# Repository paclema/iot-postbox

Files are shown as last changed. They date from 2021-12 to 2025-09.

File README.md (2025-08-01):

# IoT-PostBox



IoT-PostBox is a complete smart mailbox sensor solution that monitors mailbox activity and sends wireless notifications when events occur. The project consists of custom hardware designs with integrated battery management and charging system, and firmware that monitors switch sensors to detect mailbox events. The hardware has evolved from initial ESP8266-based designs (IoT-PostBox v0.x) to current ESP32S2-based designs (IoT-PostBox v1.x) with added LoRaWAN capabilities for extended range communication beyond WiFi and a optimized power management system. The device is designed for battery-powered operation with onboard charging circuitry. When an event is detected, the device wakes from deep sleep, connects wirelessly (WiFi or LoRa), publishes the event via MQTT or LoRaWAN, and returns to sleep to maximize battery life. The system includes device configuration and management through the WebConfigServer library, which provides a web-based dashboard to visualize data and handle device configurations easily using a config.json file.

**Installation and use:** The device is installed inside the mailbox with switches positioned to detect when the mail slot or door is opened. One switch can detect mail insertion (when the slot is opened to insert mail), while another can detect mail collection (when the mailbox door is opened to retrieve mail). This allows monitoring both mail delivery and pickup events.

**Hardware evolution:**
- **v0.x (ESP8266):** WiFi-only communication, basic power management using CH_PD pin to disable the microcontroller, battery charging system, switch sensor inputs.
- **v1.x (ESP32-S2):** Enhanced with LoRaWAN capability, improved power management with deep sleep modes managed by interrupts (allowing identification of wake-up source via WAKE_UP_BITMASK), advanced battery management, native USB programming, and expanded I/O options.

> [!NOTE]  
> For detailed hardware specifications, BOMs, and pinouts, see [`pcb_desings/readme.md`](pcb_desings/).

---

## 📁 Repository Structure

- `/src/` — Main firmware source code for IoT-PostBox
- `/pcb_desings/` — Hardware designs, documentation, BOMs, gerbers, and 3D models
- `/data/` — SPIFFS filesystem data (configs, static webapp, certificates)
- `/platformio.ini` — PlatformIO project configuration

---

## ⚡ Getting Started

1. **Select and configure your hardware:** 
   - **For IoT-PostBox PCBs:** Choose between IoT-PostBox v0.x (ESP8266-based) or IoT-PostBox v1.x (ESP32-S2-based) versions. See [`pcb_desings/readme.md`](pcb_desings/readme.md) for detailed specifications.
   - **For development boards:** The firmware also supports various ESP8266/ESP32 development boards (see available targets in `platformio.ini`), but full compatibility and functionality is only guaranteed with the custom IoT-PostBox PCBs designed for this purpose.
   - Configure the appropriate target in `platformio.ini` for your hardware version (e.g., `IoT-PostBox_v1` for IoT-PostBox v1.x PCB).
   - Edit `data/config/config.json` with your initial configuration (WiFi credentials, MQTT settings, etc.) following the WebConfigServer library standard.

2. **Upload SPIFFS data:**
   ```sh
   pio run -t uploadfs
   ```

3. **Build and upload firmware:** Use PlatformIO to compile and flash the firmware to your device.

4. **Configure the device:** Access the web dashboard hosted by the device for WiFi, MQTT, and power management setup, or update the configuration by editing `config.json` and re-uploading SPIFFS data.

---

## 📈 Web Dashboard

The static web dashboard is provided by the [WebConfigServer](https://github.com/paclema/WebConfigServer) library and served directly from the device.

If you need to customize the dashboard:
- Go to the WebConfigServer repository and follow the build instructions
- Copy the generated static files to the `/data/` folder
- Upload `/data/` to the device SPIFFS

---

## 📚 Dependencies

This project uses the following main libraries:
- [WebConfigServer](https://github.com/paclema/WebConfigServer) - Web dashboard and device configuration management
- [PowerManagement](https://github.com/paclema/PowerManagement) - Battery monitoring and power management

---

## 📄 License

[][cc-by-nc-sa]&nbsp;&nbsp;&nbsp;<a property="dct:title" rel="cc:attributionURL" href="https://github.com/paclema/iot-postbox"> IoT-PostBox</a> © 2019-2025 by <a rel="cc:attributionURL dct:creator" property="cc:attributionName" href="http://www.paclema.com/">paclema</a> is licensed under <a href="http://creativecommons.org/licenses/by-nc-sa/4.0/?ref=chooser-v1" target="_blank" rel="license noopener noreferrer" style="display:inline-block;">CC BY-NC-SA 4.0</a>

**Hardware and firmware designs** are provided for educational and non-commercial use. For commercial use, please contact the author for permission.

[cc-by-nc-sa]: http://creativecommons.org/licenses/by-nc-sa/4.0/
[cc-by-nc-sa-image]: https://licensebuttons.net/l/by-nc-sa/4.0/88x31.png

---

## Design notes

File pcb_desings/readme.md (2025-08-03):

# IoT-PostBox PCB Designs

This folder contains all hardware designs for the IoT-PostBox project. These PCBs are intended for ultra-low power event detection and wireless notification, ideal for smart mailboxes or similar battery-powered IoT applications. The boards are designed to maximize battery life by staying in deep sleep and only waking up when an event is detected.  
**Typical use case:** Mount a switch at the mailbox slot or door to detect when a letter or package is inserted, triggering a wireless notification.

---

## 📝 How It Works

- **Event Detection:** The boards monitor switches (J1/J2) for events such as mailbox opening or mail insertion.
- **Wake-Up:** ESP8266 boards power on from switches, ESP32-S2 boards wake from deep sleep via GPIO interrupts
- **Notification:** Events are sent wirelessly (WiFi/MQTT for ESP8266, WiFi/MQTT and LoRaWAN for ESP32-S2)
- **Power Management:** Battery charging and monitoring circuits ensure safe operation and long battery life.

---

## 📦 IoT-Postbox v0.X (ESP8266/ESP-12)

- **Folder:** [`iot-postbox/`](iot-postbox/)
- **MCU:** ESP8266 (ESP-12F or ESP-07S)
- **Wake-up:** When either switch input (J1 or J2) closes, it physically pulls the CH_PD pin high, powering on the ESP8266 from a completely powered-down state. Once powered on, the firmware immediately activates GPIO14 to maintain CH_PD high, ensuring the system stays powered even if the switch opens during the notification process. After completing the notification and a configured delay, GPIO14 goes low, completely powering down the ESP8266 for maximum battery savings. The board can also be configured for deep sleep mode or continuous operation instead of complete power down via the onboard web app.
- **Features:**
  - Battery charger (TP4056) with overcharge, overdischarge, and overcurrent protection
  - Power management with LDO (candidates: ME6211 or MCP1700)
  - Switch sensor inputs for mailbox event detection
  - Deep sleep and wake-up logic via GPIO
  - WiFi and MQTT notifications for remote monitoring
- **Versions:**
  | v0.0 | v0.3 |
  |:----:|:----:|
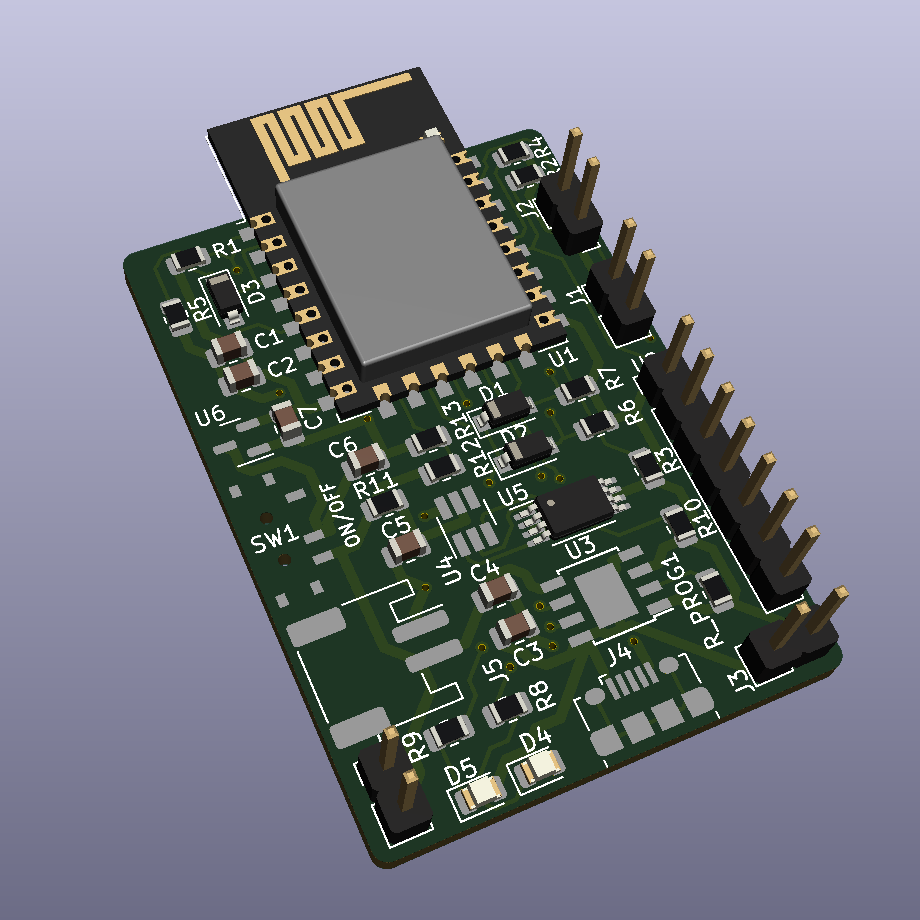
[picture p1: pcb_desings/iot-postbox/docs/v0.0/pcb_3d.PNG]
v0.0
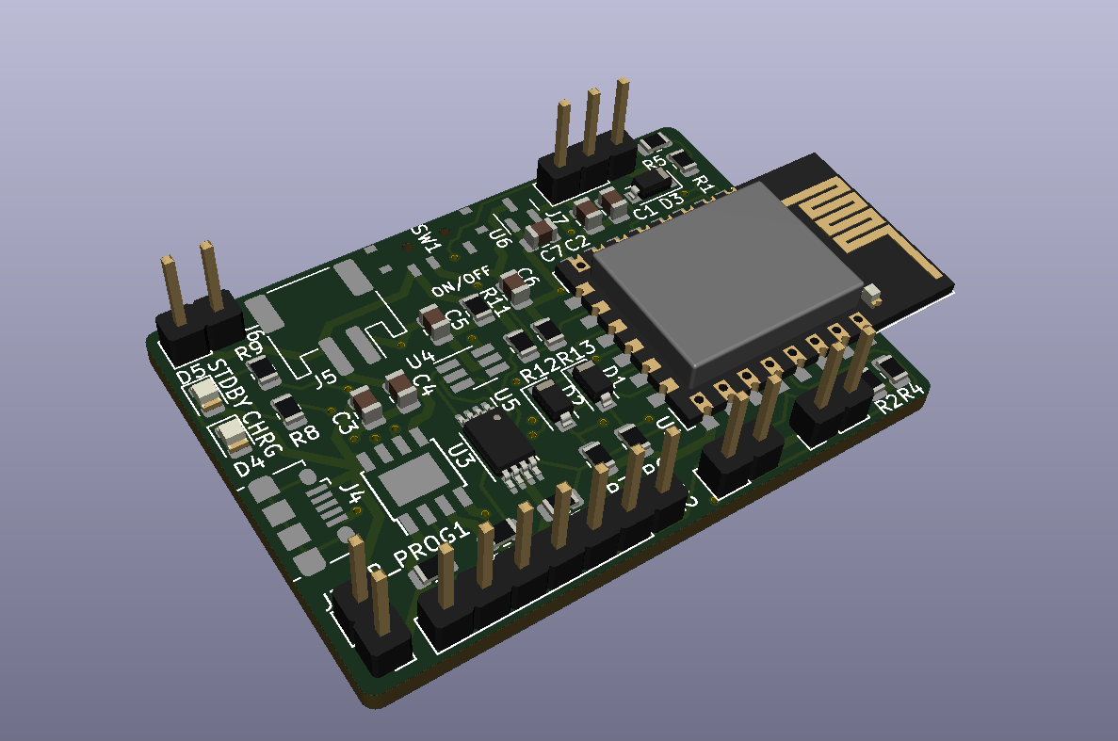
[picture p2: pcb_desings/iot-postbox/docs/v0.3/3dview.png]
v0.3
  |  |  |
  | *First version* <br> Basic mailbox sensor with battery charger and power management. | *Added WS2812B LED strip for notifications* <br> *Updated battery sense resistors for improved ADC accuracy* <br> *Changed switch pinouts for better integration* |

- **Programming & Debugging:**  
  For ESP8266-based boards, external programming is required. Two options available:
  
  **Option 1: TTL-to-USB Adapter + FTDI Breakout**
  | Top View | Bottom View |
  |:------------------:|:----------------:|
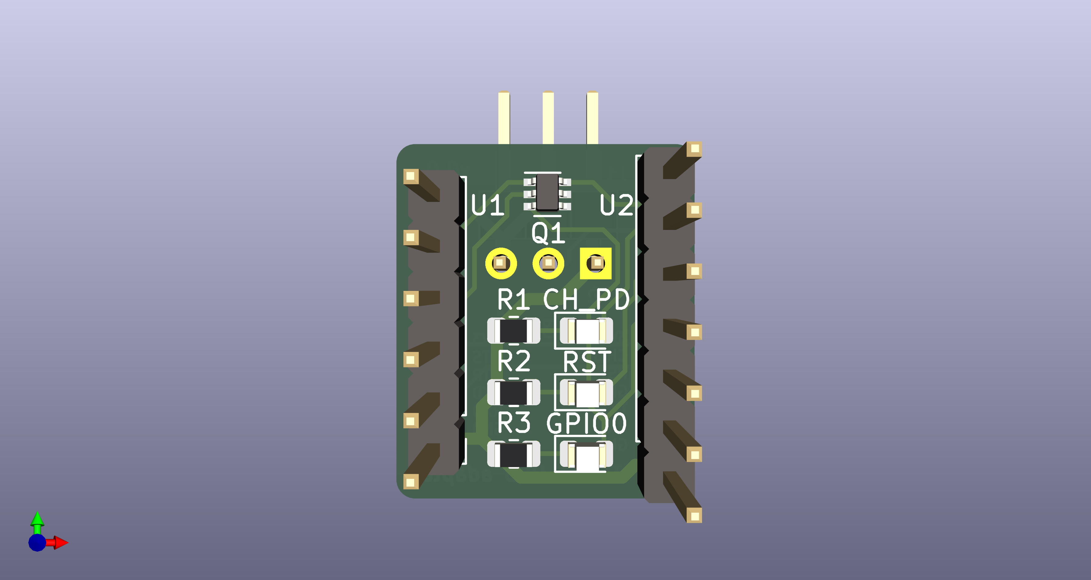
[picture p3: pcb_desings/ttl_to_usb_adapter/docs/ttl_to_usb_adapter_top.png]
TTL Adapter TTL to USB Adapter
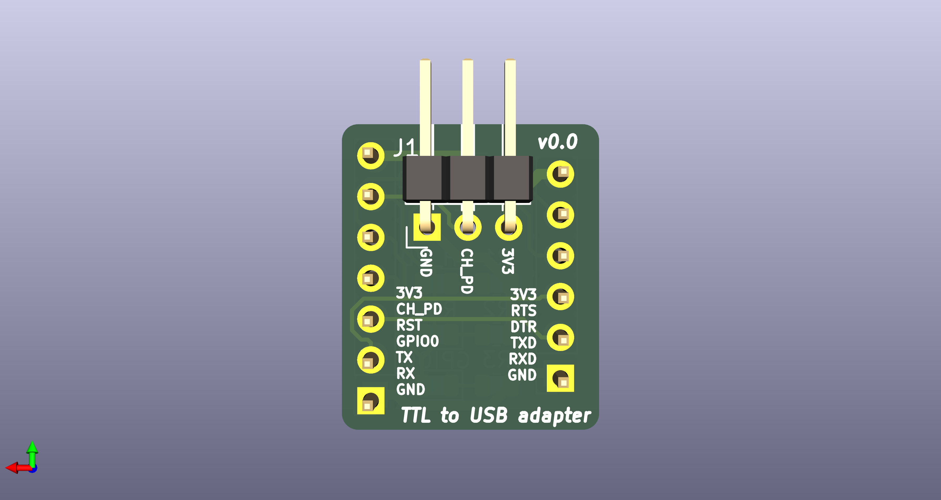
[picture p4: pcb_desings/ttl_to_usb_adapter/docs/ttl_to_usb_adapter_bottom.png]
TTL Adapter SMD
  |  |  |
  - **Repository:** [`ttl_to_usb_adapter/`](ttl_to_usb_adapter/)
  - Converts DTR/RTS signals from an USB to Serial FTDI breakout board to ESP8266 boot sequence
  - Dedicated jumper for CH_PD control during programming

  **Option 2: Integrated USB Bridge**
  - **USBtoUART:** Complete solution available at [paclema.com/projects/usbtouart/](https://paclema.com/projects/usbtouart/) or at github.com/paclema/USBtoUART
  - Single device with integrated USB-to-UART conversion

---

## 📦 IoT-Postbox v1 (ESP32-S2)

- **Folder:** [`iot-postbox_v1/`](iot-postbox_v1/)
- **MCU:** ESP32-S2
- **Wake-up:** Switches (J1/J2) are configured as GPIO interrupts to wake up the MCU from deep sleep, instead of physically powering on the board (as in ESP8266). This allows more flexible event handling and enables distinguishing between different events.
- **Features:**
  - LoRa support (RFM95W module footprints)
  - Up to 16MB flash and 8MB PSRAM (optional, depending on SoC version)
  - Improved battery and power management (dedicated ADC sense for VBAT and VBUS)
  - Modular schematic split into INTERFACE, MCU, and POWER sections
  - Selectable onboard/uFL antennas for WiFi (JP1) and LoRa (JP2) by populating the correct resistor
  - Dedicated JTAG debug port
  - Multiple jumpers and test points on the back for configuration and debugging (including RPROG selection for battery charger IC)

- **Latest version:** IoT-PostBox v1.2
  | Top View | Bottom View |
  |:--------------:|:----------------:|
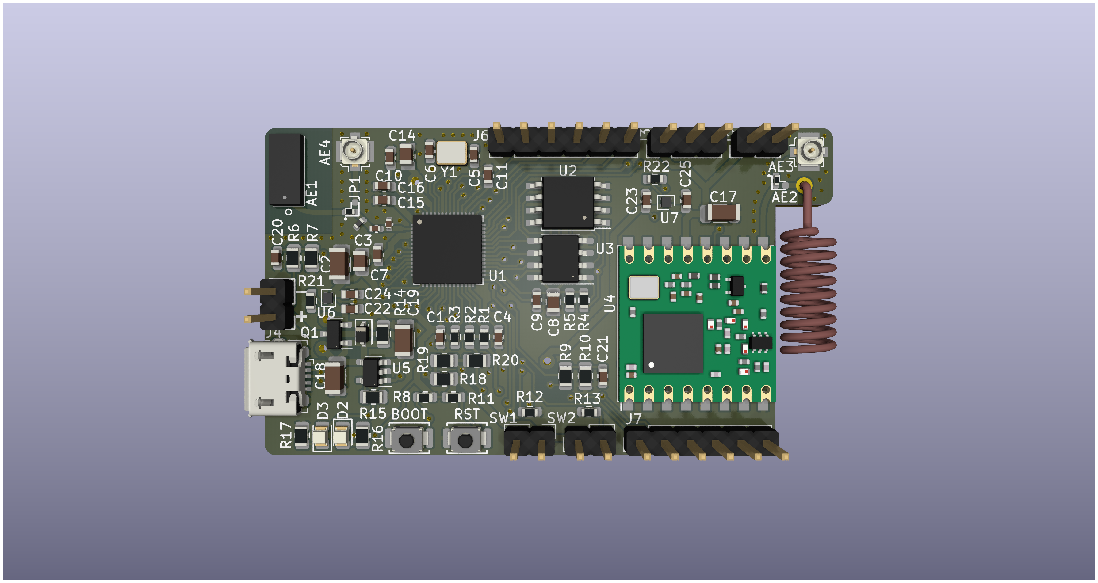
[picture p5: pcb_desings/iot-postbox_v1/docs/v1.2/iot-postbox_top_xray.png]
Top v1.2 Top
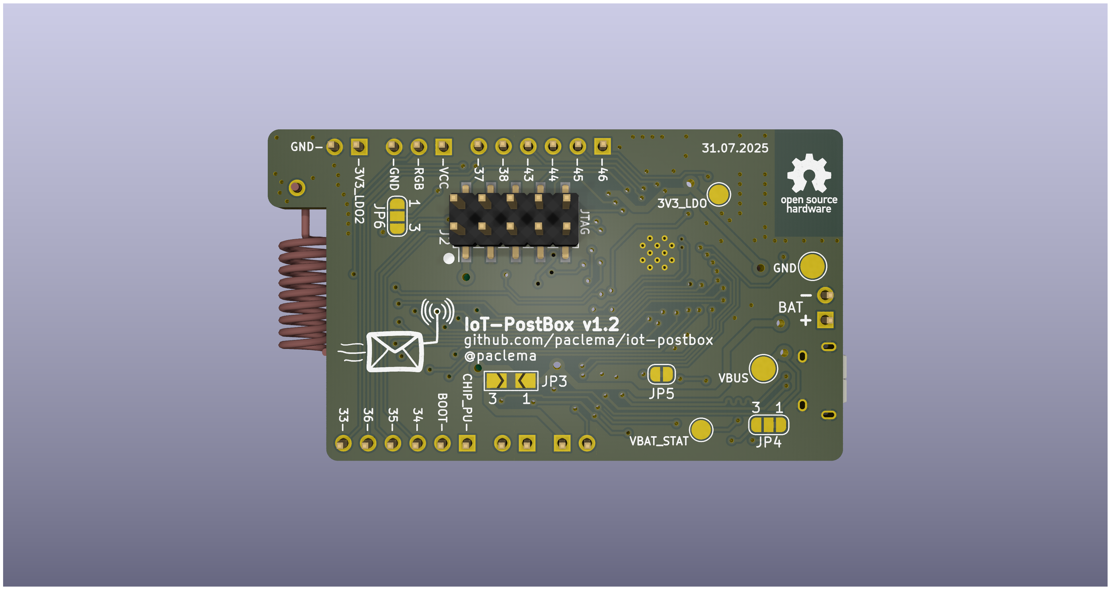
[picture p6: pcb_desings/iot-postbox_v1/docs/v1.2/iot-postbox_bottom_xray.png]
Bottom v1.2 Bottom
  |  |  |

- **Programming & Debugging:**  
  Programming and debugging for the ESP32-S2 board does **not require an external USB-to-UART bridge**. The ESP32-S2 features a native USB interface (USB-CDC/JTAG), allowing direct programming and serial communication via the onboard USB connector. Simply connect the board to your computer using a USB cable for firmware flashing and debugging.

### LiPo Charger & RPROG Selection

The onboard charger circuit is designed to be compatible with MCP73831/2, TP4054, and TP4065 ICs, allowing any of these to be used. The charging current is set by the RPROG resistor.

- **For MCP73831/2 (max 500mA) and TP4054 (max 800mA):**
  ```
  Ichg (mA) = 1000(v) / R(kΩ)
  ```
  | RPROG (Ω) | Charging Current (mA) |
  |-----------|----------------------|
  | 10k       | 100                  |
  | 5k        | 200                  |
  | 2k2       | 455                  |
  | 2k        | 500                  |
  | 1k        | 1000                 |

- **For TP4065 (max 600mA):**
  ```
  Ichg (mA) = 1100(v) / R(kΩ)
  ```
  | RPROG (Ω) | Charging Current (mA) |
  |-----------|----------------------|
  | 2k2       | 500                  |
  | 2k        | 600                  |

- **Note:**  
  - Choose the RPROG value based on your battery's specifications and desired charging speed.
  - Protections: Battery and input reverse polarity protection but no temperature or overcurrent protection.

- **VBAT_STAT output:**  
  - Tri-state output: for MCP73831.
  - Open-drain output: for MCP7383, TP4054 and TP4065.
  - Only for open-drain, `R18` makes sense because VDD_STAT can be configurable only in that case.
  - Monitored using ESP32-S2 GPIO3/ADC1_CH2 pin.

### Pinout Reference (IoT-Postbox v1.2)

Below are the pinouts for the main connectors on the back of the IoT-Postbox v1.2 PCB, including signal and ESP32-S2 functions:

#### J6 (EXT1 Expansion Port):

| Pin | Signal | Function |
|-----|---|---|
| 1 | GPIO46 | Strapping pin (can be used for boot mode selection) |
| 2 | GPIO45 | Strapping pin (can be used for VDD_SPI selection) |
| 3 | GPIO44 | UART0 RXD (default) |
| 4 | GPIO43 | UART0 TXD (default) |
| 5 | GPIO38 | I2C SCL (default) |
| 6 | GPIO37 | SPI MISO (default) |

#### J3 (LED Port):

| Pin | Signal | Function |
|-----|---|---|
| 1 | VCC | Power for LED strip (3V3_LDO2) |
| 2 | RGB_LED_PWM | PWM output for RGB LED strip |
| 3 | GND | Ground |

#### J5 (Power Output Port):

| Pin | Signal | Function |
|-----|---|---|
| 1 | 3V3_LDO2 | Power output from peripheral LDO |
| 2 | GND | Ground |

#### SW1 (Switch Sensor 1):

| Pin | Signal | Function |
|-----|---|---|
| 1 | 3V3_LDO  | Power for switch sensor |
| 2 | SW1 | Digital input (event detection, GPIO input) |

#### SW2 (Switch Sensor 2):

| Pin | Signal | Function |
|-----|---|---|
| 1 | 3V3_LDO  | Power for switch sensor |
| 2 | SW2 | Digital input (event detection, GPIO input) |

#### J7 (EXT2 Expansion Port):

| Pin | Signal | Function |
|-----|---|---|
| 1 | CHIP_PU  | ESP32-S2 enable (power up, active high) |
| 2 | BOOT | Boot mode selection (GPIO0, strapping pin) |
| 3 | GPIO34 | SPI MOSI (default) |
| 4 | GPIO35 | SPI SCK (default) |
| 5 | GPIO36 | SPI CS (default) |
| 6 | GPIO33 | I2C SDA (default) |

---

### 📚 Libraries

- **Folder:** [`libs/`](libs/)
- Contains KiCad symbols, footprints and 3D models, including Espressif official libraries and miscellaneous modules.

---

### 🛠️ Submodules Installation for KiCad

To pull KiCad lib submodules, run:
```sh
git submodule update --init --recursive
```

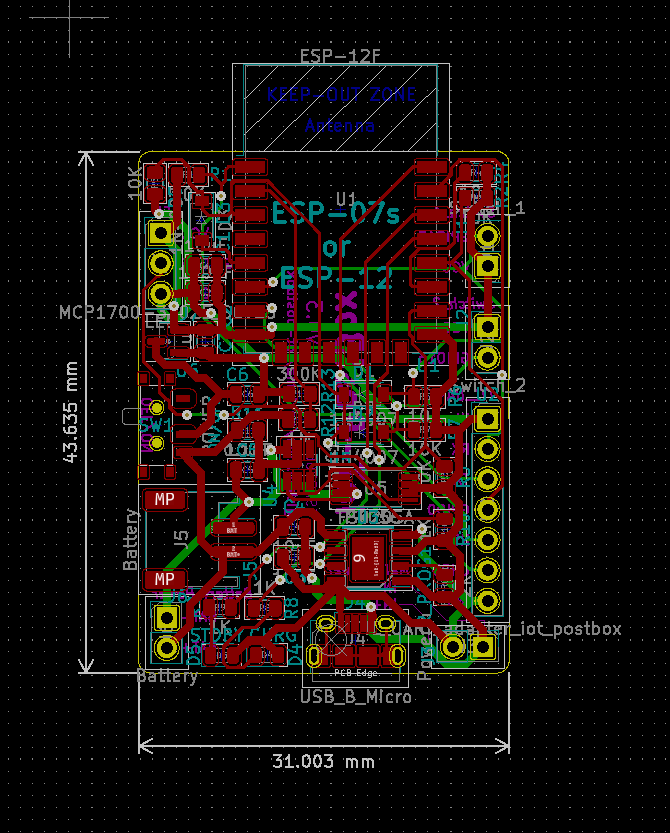
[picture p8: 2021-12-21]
pcb_desings/iot-postbox/docs/v0.3/pcb_view.png

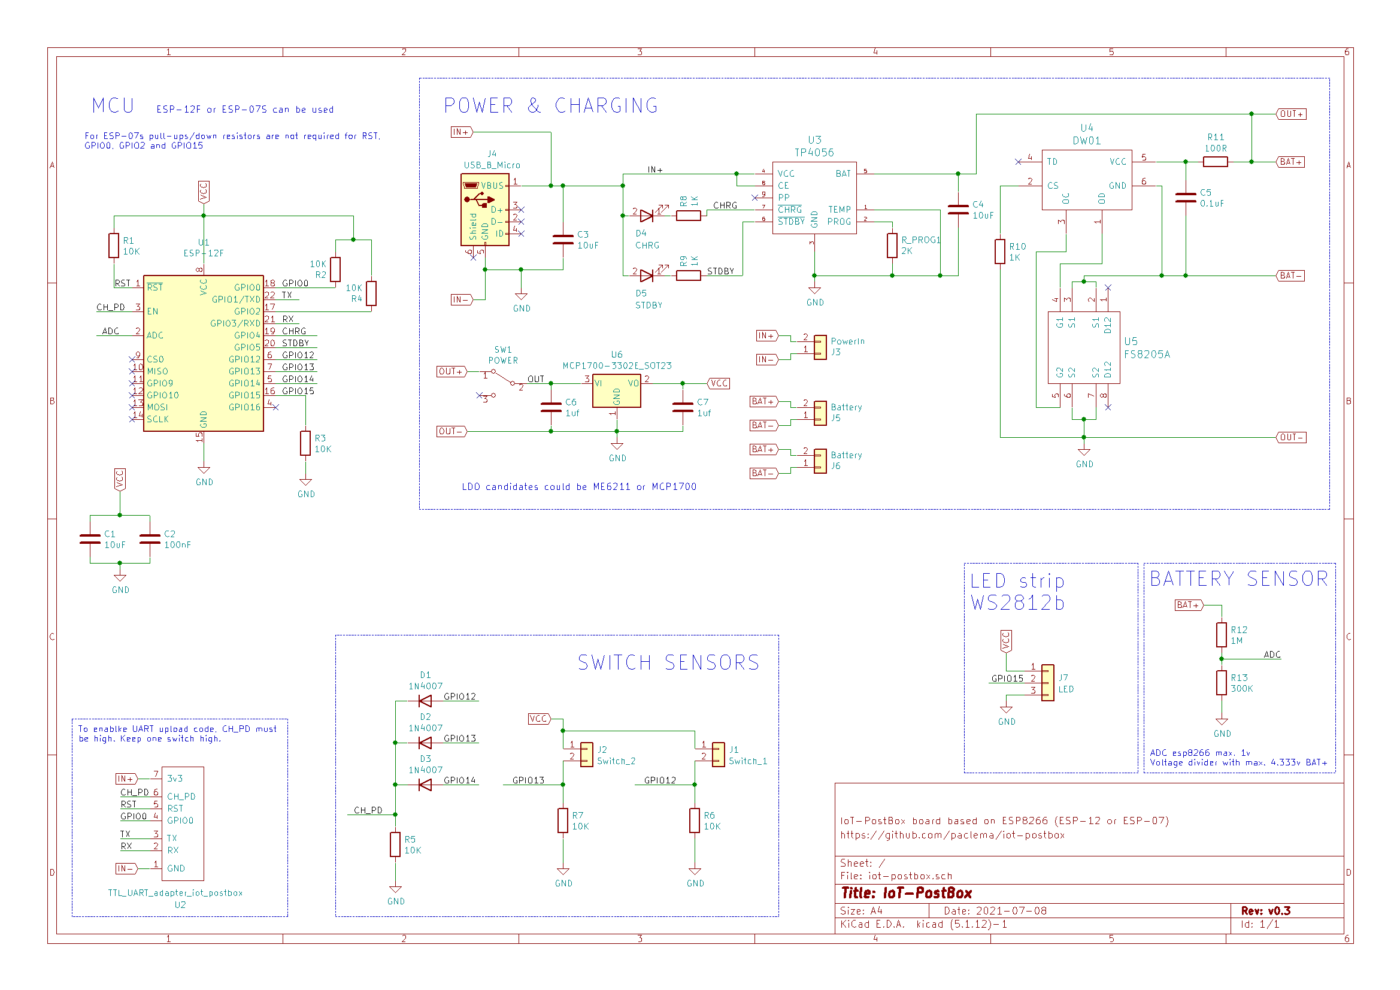
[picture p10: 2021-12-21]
pcb_desings/iot-postbox/docs/v0.3/sch_view.png

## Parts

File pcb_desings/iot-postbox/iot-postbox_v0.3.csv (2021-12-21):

Id | Designator | Package | Quantity | Designation | Supplier and ref
1 | J7 | PinHeader_1x03_P2.54mm_Vertical | 1 | LED
2 | U2 | PinHeader_1x07_P2.54mm_Vertical | 1 | TTL_UART_adapter_iot_postbox
3 | SW1 | 1P2T_SPDT_MSK-C02_7pin | 1 | POWER
4 | U6 | SOT-23 | 1 | MCP1700-3302E_SOT23
5 | U5 | TSSOP-8_4.4x3mm_P0.65mm | 1 | FS8205A
6 | U4 | SOT-23-6_Handsoldering | 1 | DW01
7 | U3 | TP4056_SOP-8-PP | 1 | TP4056
8 | U1 | ESP-12E | 1 | ESP-12F
9 | R_PROG1 | R_0805_2012Metric | 1 | 2K
10 | R13 | R_0805_2012Metric | 1 | 300K
11 | R12 | R_0805_2012Metric | 1 | 1M
12 | R11 | R_0805_2012Metric | 1 | 100R
13 | R10,R9,R8 | R_0805_2012Metric | 3 | 1K
14 | R6,R7,R5,R4,R3,R2,R1 | R_0805_2012Metric | 7 | 10K
15 | J6 | PinHeader_1x02_P2.54mm_Vertical | 1 | Battery
16 | J5 | JST_PH_S2B-PH-SM4-TB_1x02-1MP_P2.00mm_Horizontal | 1 | Battery
17 | J4 | USB_Micro-B_Amphenol_10118194_Horizontal | 1 | USB_B_Micro
18 | J3 | PinHeader_1x02_P2.54mm_Vertical | 1 | PowerIn
19 | J1 | PinHeader_1x02_P2.54mm_Vertical | 1 | Switch_1
20 | J2 | PinHeader_1x02_P2.54mm_Vertical | 1 | Switch_2
21 | D5 | LED_0805_2012Metric | 1 | STDBY
22 | D4 | LED_0805_2012Metric | 1 | CHRG
23 | D3,D2,D1 | D_SOD-123 | 3 | 1N4007
24 | C7,C6 | C_0805_2012Metric | 2 | 1uf
25 | C5 | C_0805_2012Metric | 1 | 0.1uF
26 | C4,C3,C1 | C_0805_2012Metric | 3 | 10uF
27 | C2 | C_0805_2012Metric | 1 | 100nF

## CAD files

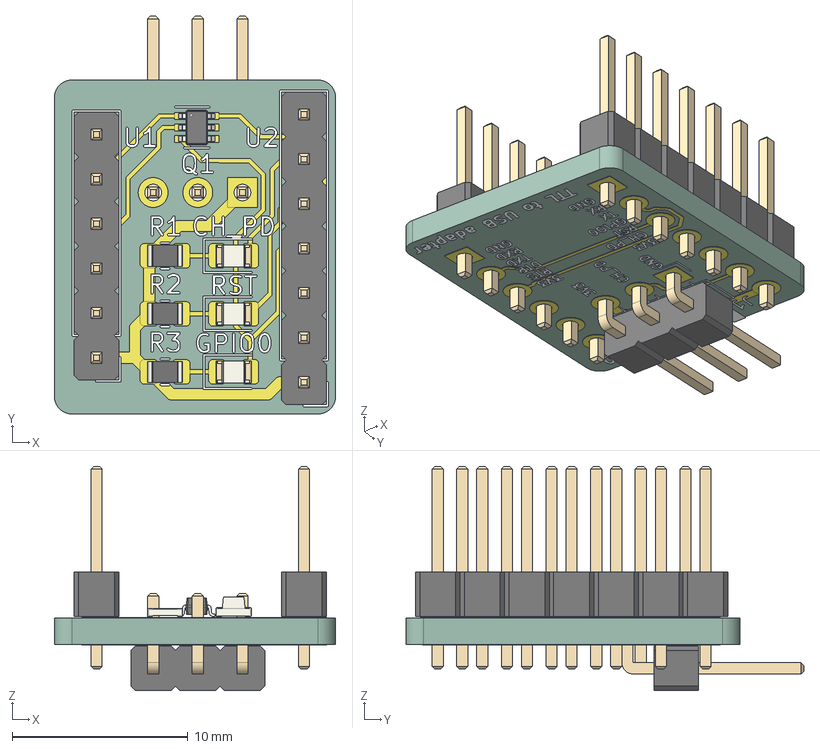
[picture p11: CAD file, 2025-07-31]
pcb_desings/ttl_to_usb_adapter/docs/ttl_to_usb_adapter.step
16.0 x 22.6 x 12.8 mm
PinHeader_1x06_P2.54mm_Vertical
SOT-363_SC-70-6
LED_0805_2012Metric x 3
R_0805_2012Metric x 3
PinHeader_1x07_P2.54mm_Vertical
PinHeader_1x03_P2.54mm_Horizontal
ttl_to_usb_adapter_copper
ttl_to_usb_adapter_silkscreen
ttl_to_usb_adapter_PCB

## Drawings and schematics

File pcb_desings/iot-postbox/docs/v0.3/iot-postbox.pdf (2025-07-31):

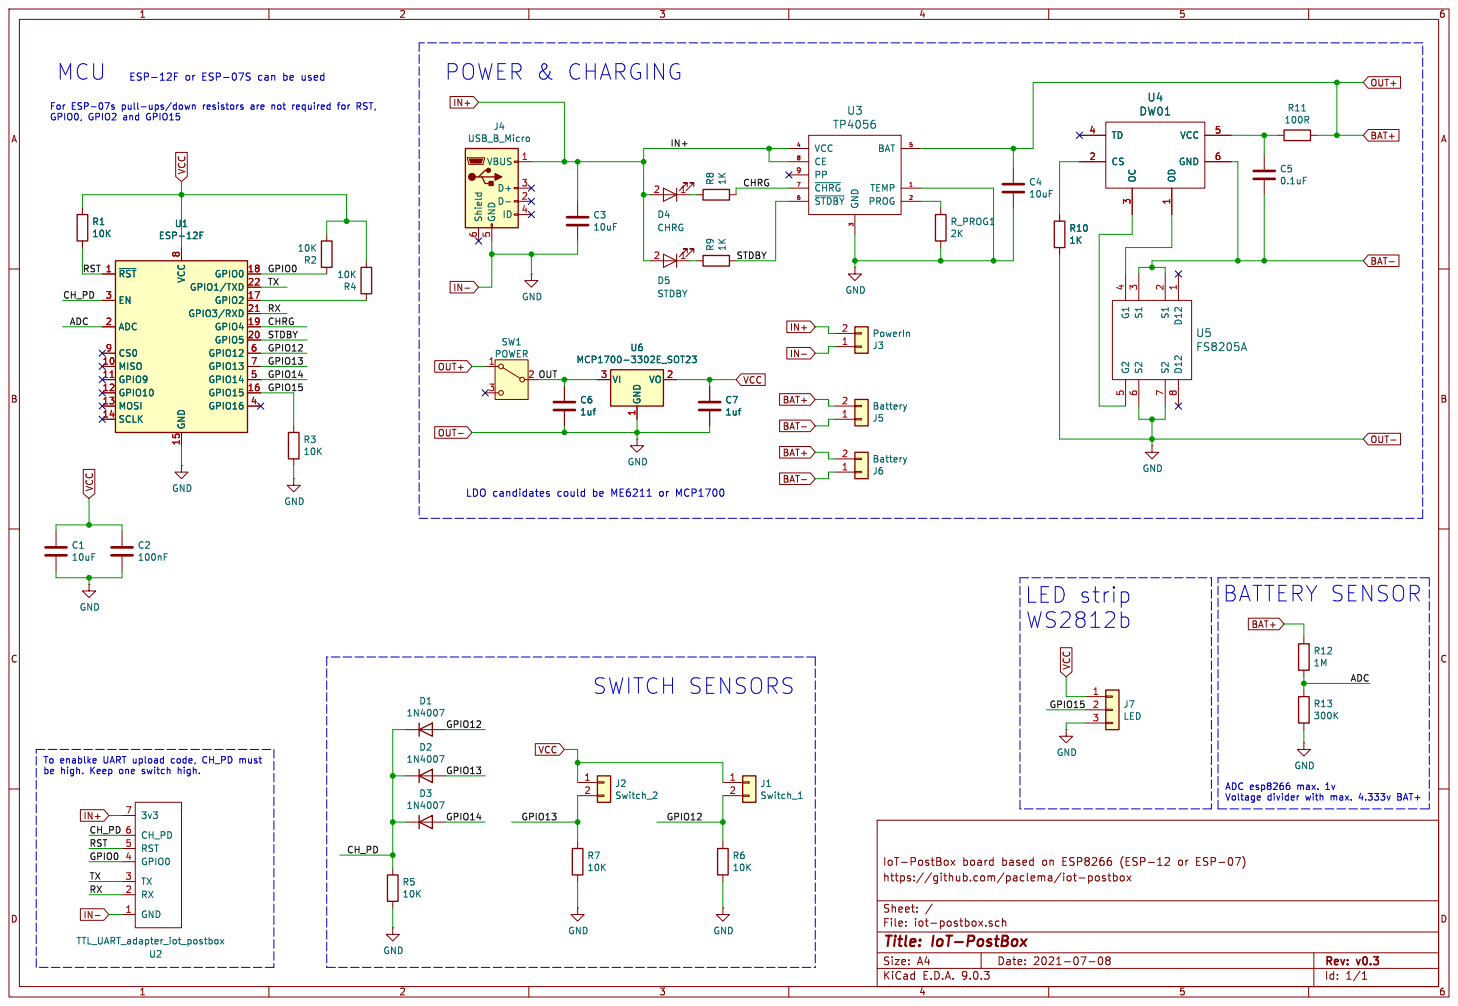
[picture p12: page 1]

BAT- BAT+ OUT+ OUT- BAT+ BAT-

8 GND 15 GPIO0 18 GPIO1/TXD 22 GPIO2 17 GPIO3/RXD 21 GPIO4 19 GPIO5 20 GPIO12 6 GPIO13 7 GPIO14 5 GPIO15 16 GPIO16 4 U1 ESP-12F

8 GND 15 GPIO0 18 GPIO1/TXD 22 GPIO2 17 GPIO3/RXD 21 GPIO4 19 GPIO5 20 GPIO12 6 GPIO13 7 GPIO14 5 GPIO15 16 GPIO16 4 U6 MCP1700-3302E_SOT23 VI 3 GND

File: iot-postbox.sch Sheet: / https://github.com/paclema/iot-postbox

Id: 1/1 Title: IoT-PostBox

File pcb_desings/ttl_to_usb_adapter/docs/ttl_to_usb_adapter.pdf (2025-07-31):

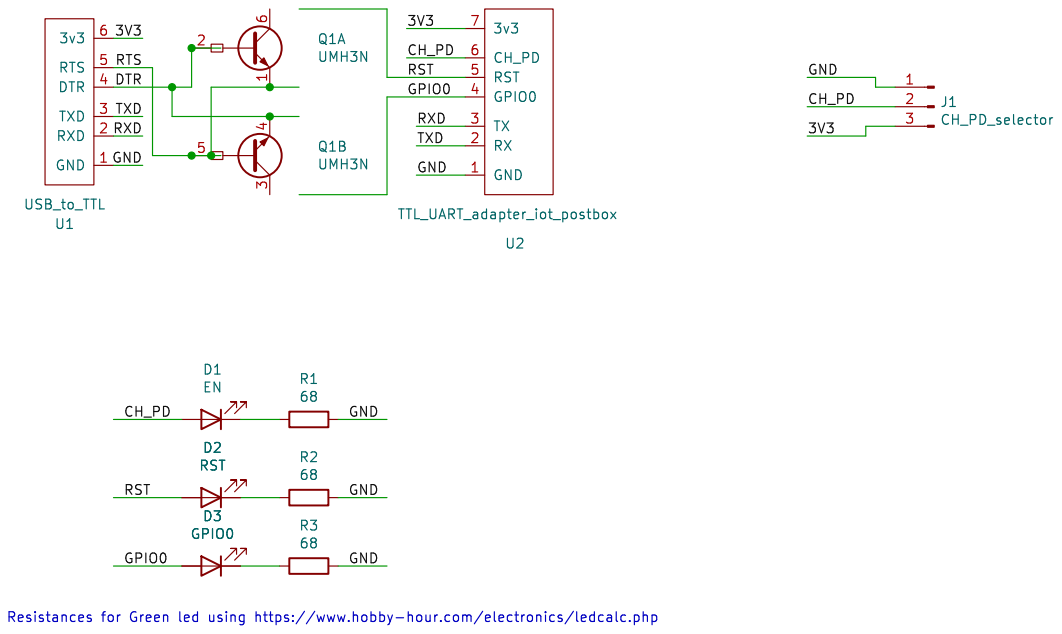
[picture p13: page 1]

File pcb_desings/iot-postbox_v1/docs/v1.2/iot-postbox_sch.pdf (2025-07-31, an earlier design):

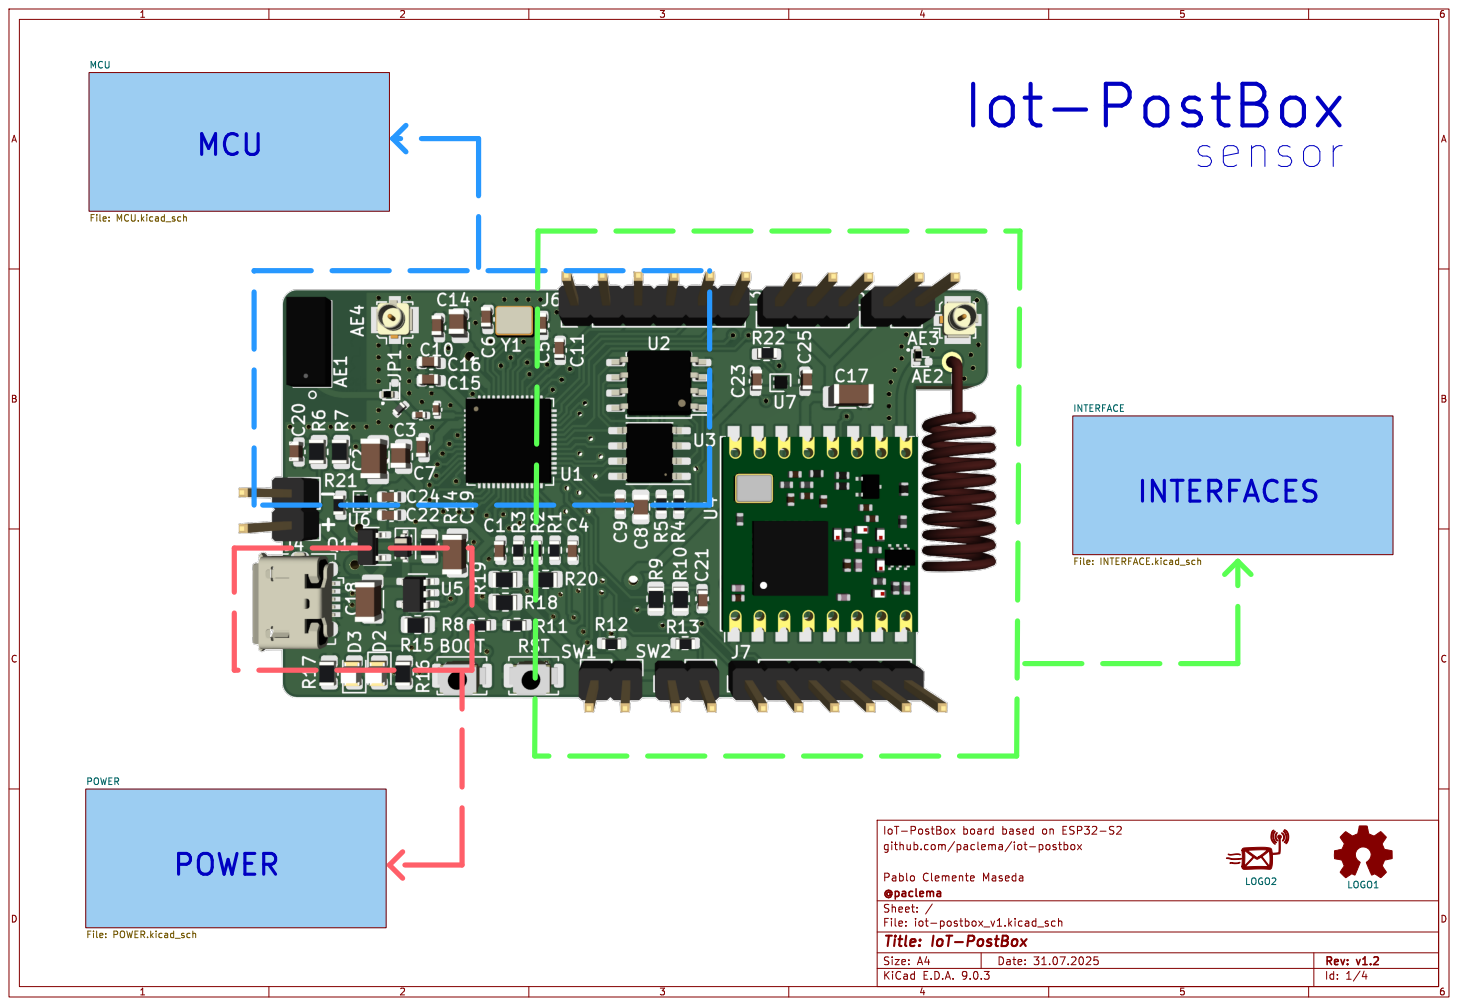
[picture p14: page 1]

github.com/paclema/iot-postbox

POWER

File: iot-postbox_v1.kicad_sch Sheet: / @paclema Pablo Clemente | Maseda

Id: 1/4 Title: IoT-PostBox

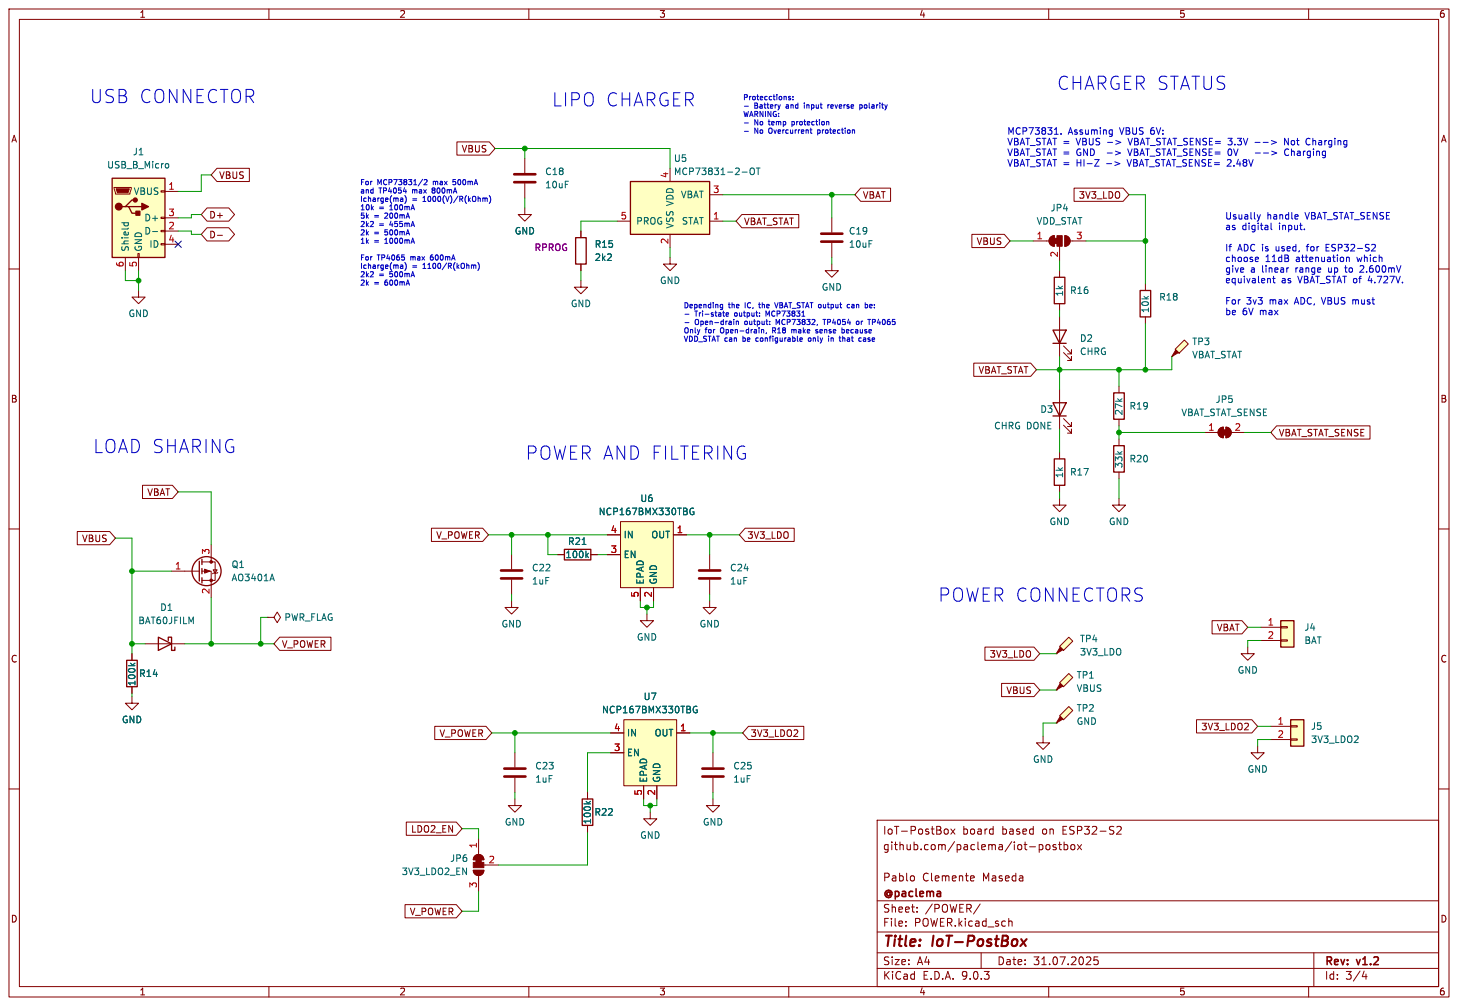
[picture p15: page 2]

Protecctions: - Battery and input reverse polarity WARNING: - No temp protection
100k VBUS
100k GND
2k2 RPROG

2 VBAT 3 STAT 1 U5 MCP73831-2-OT GND

If ADC is used, for ESP32-S2
give a linear range up to 2.600mV

GND GND

github.com/paclema/iot-postbox

Id: 3/4 Title: IoT-PostBox

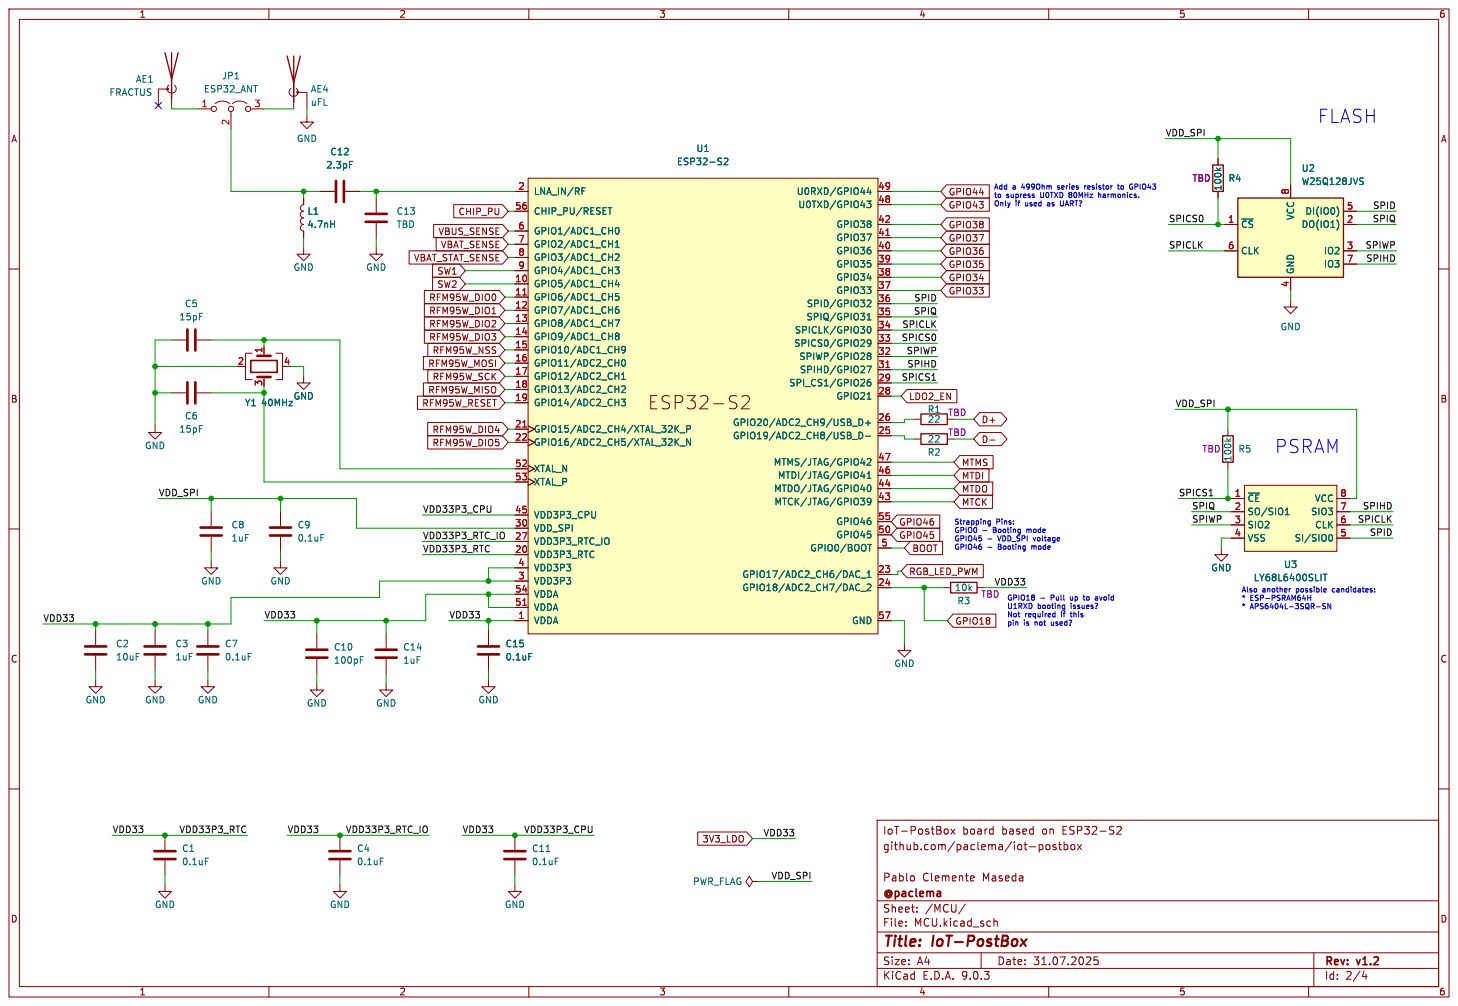
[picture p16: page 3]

github.com/paclema/iot-postbox

Id: 2/4 Title: IoT-PostBox

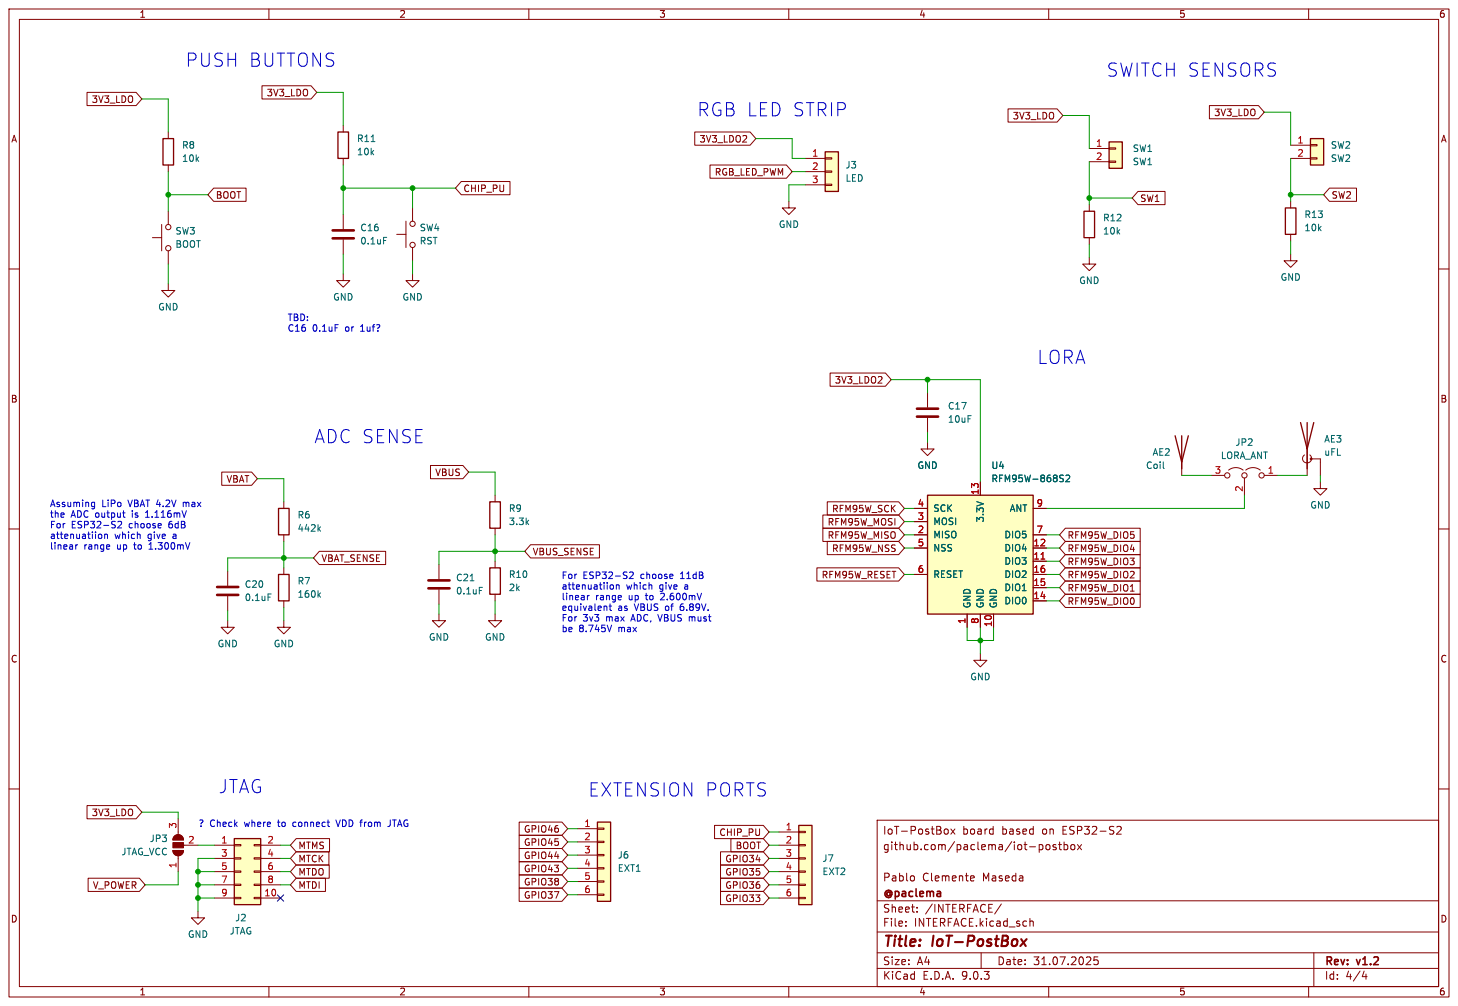
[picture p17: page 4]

Assuming LiPo VBAT 4.2V max
the ADC output is 1.116mV

linear range up to 2.600mV

github.com/paclema/iot-postbox

Id: 4/4 Title: IoT-PostBox

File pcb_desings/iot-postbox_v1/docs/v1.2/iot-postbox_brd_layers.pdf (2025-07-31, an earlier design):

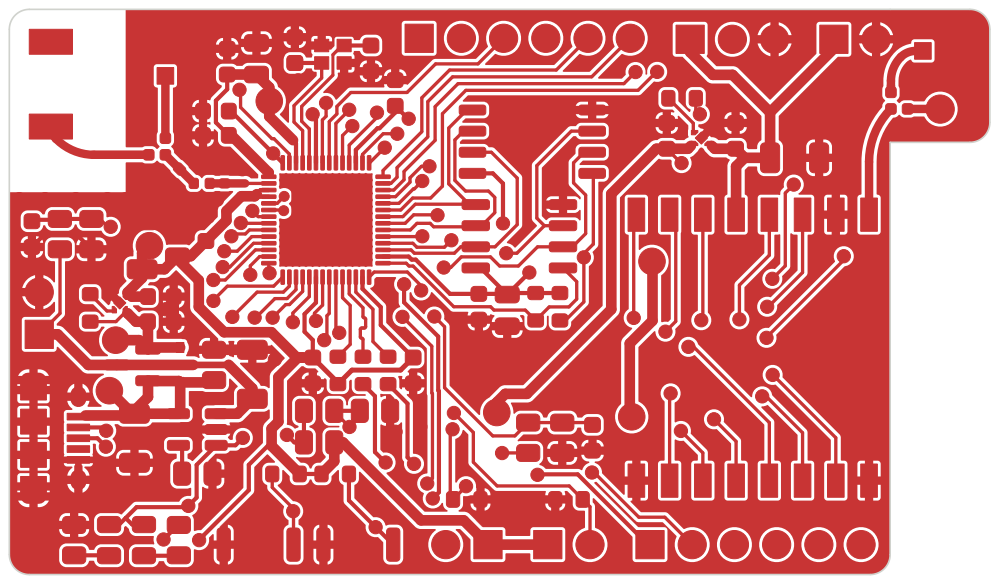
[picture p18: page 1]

github.com/paclema/iot-postbox

Id: 1/11 Title: IoT-PostBox

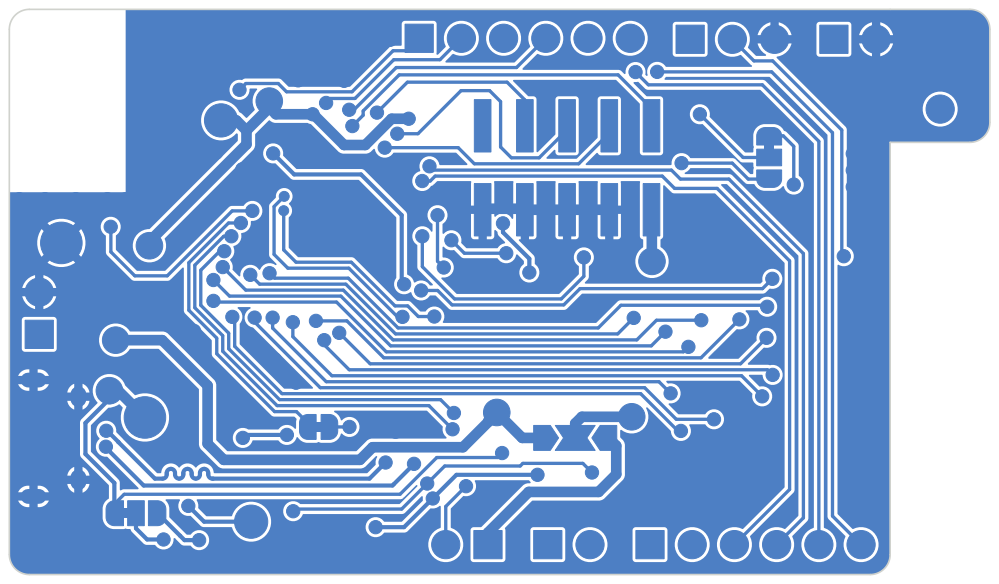
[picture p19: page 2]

github.com/paclema/iot-postbox

Id: 2/11 Title: IoT-PostBox

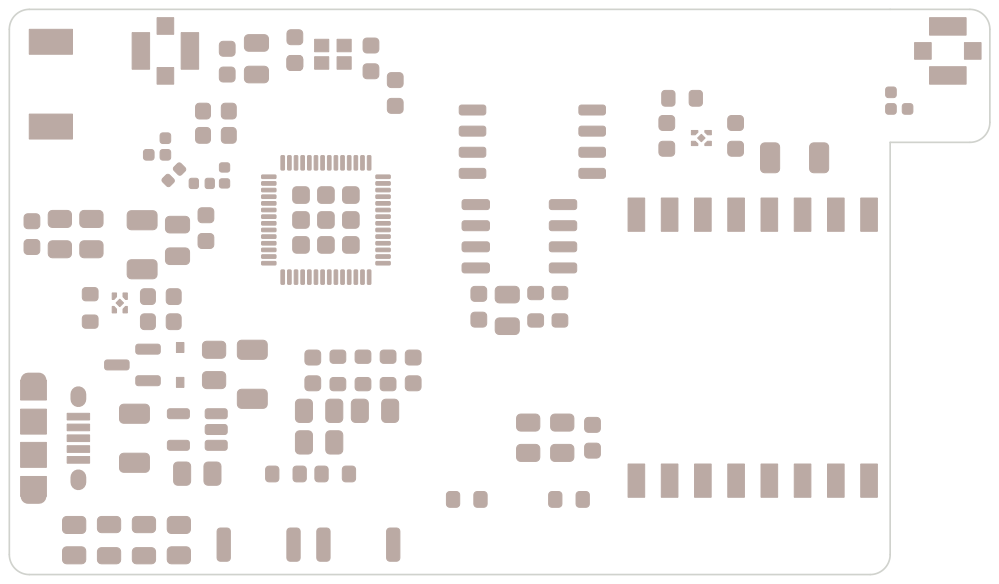
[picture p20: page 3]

github.com/paclema/iot-postbox

Id: 3/11 Title: IoT-PostBox

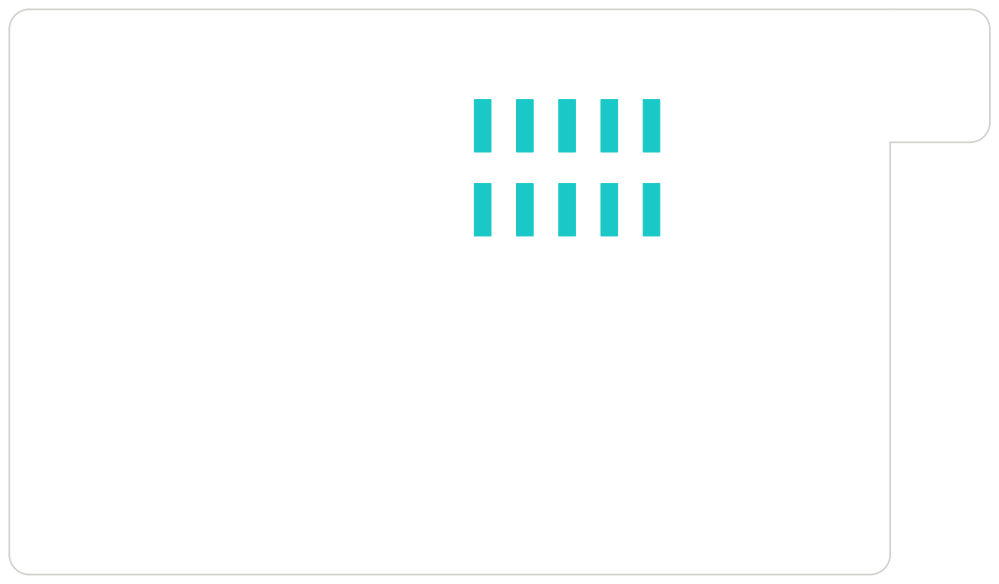
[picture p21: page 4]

github.com/paclema/iot-postbox

Id: 4/11 Title: IoT-PostBox

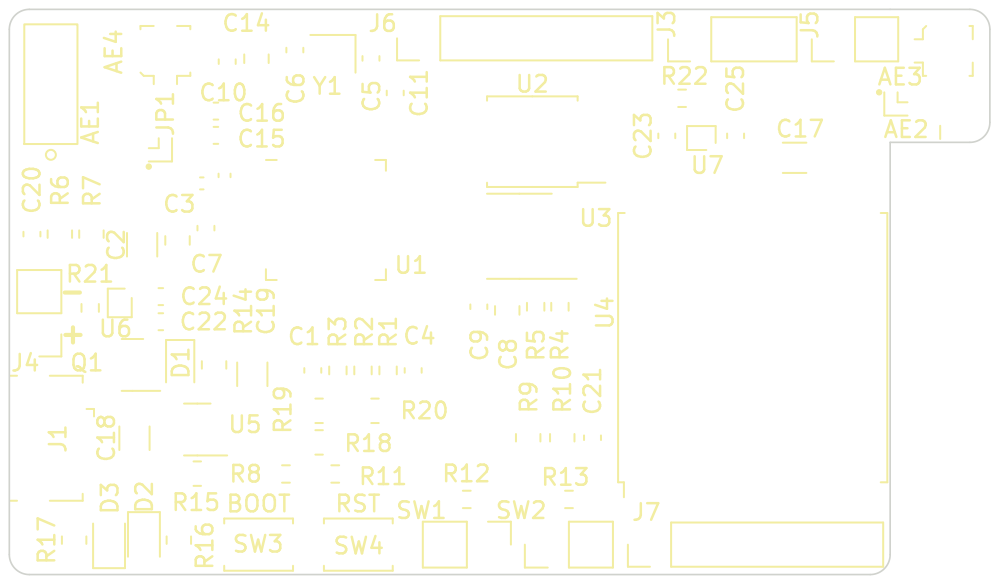
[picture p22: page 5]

github.com/paclema/iot-postbox

Id: 5/11 Title: IoT-PostBox

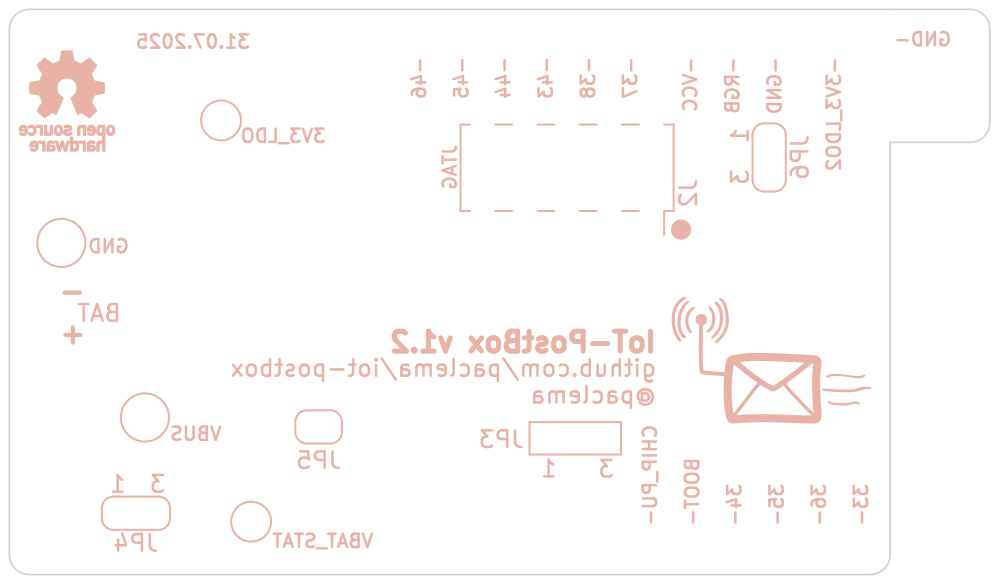
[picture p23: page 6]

github.com/paclema/iot-postbox

Id: 6/11 Title: IoT-PostBox


github.com/paclema/iot-postbox

Id: 7/11 Title: IoT-PostBox


github.com/paclema/iot-postbox

Id: 8/11 Title: IoT-PostBox


github.com/paclema/iot-postbox

Id: 9/11 Title: IoT-PostBox


github.com/paclema/iot-postbox

Id: 10/11 Title: IoT-PostBox


github.com/paclema/iot-postbox

Id: 11/11 Title: IoT-PostBox







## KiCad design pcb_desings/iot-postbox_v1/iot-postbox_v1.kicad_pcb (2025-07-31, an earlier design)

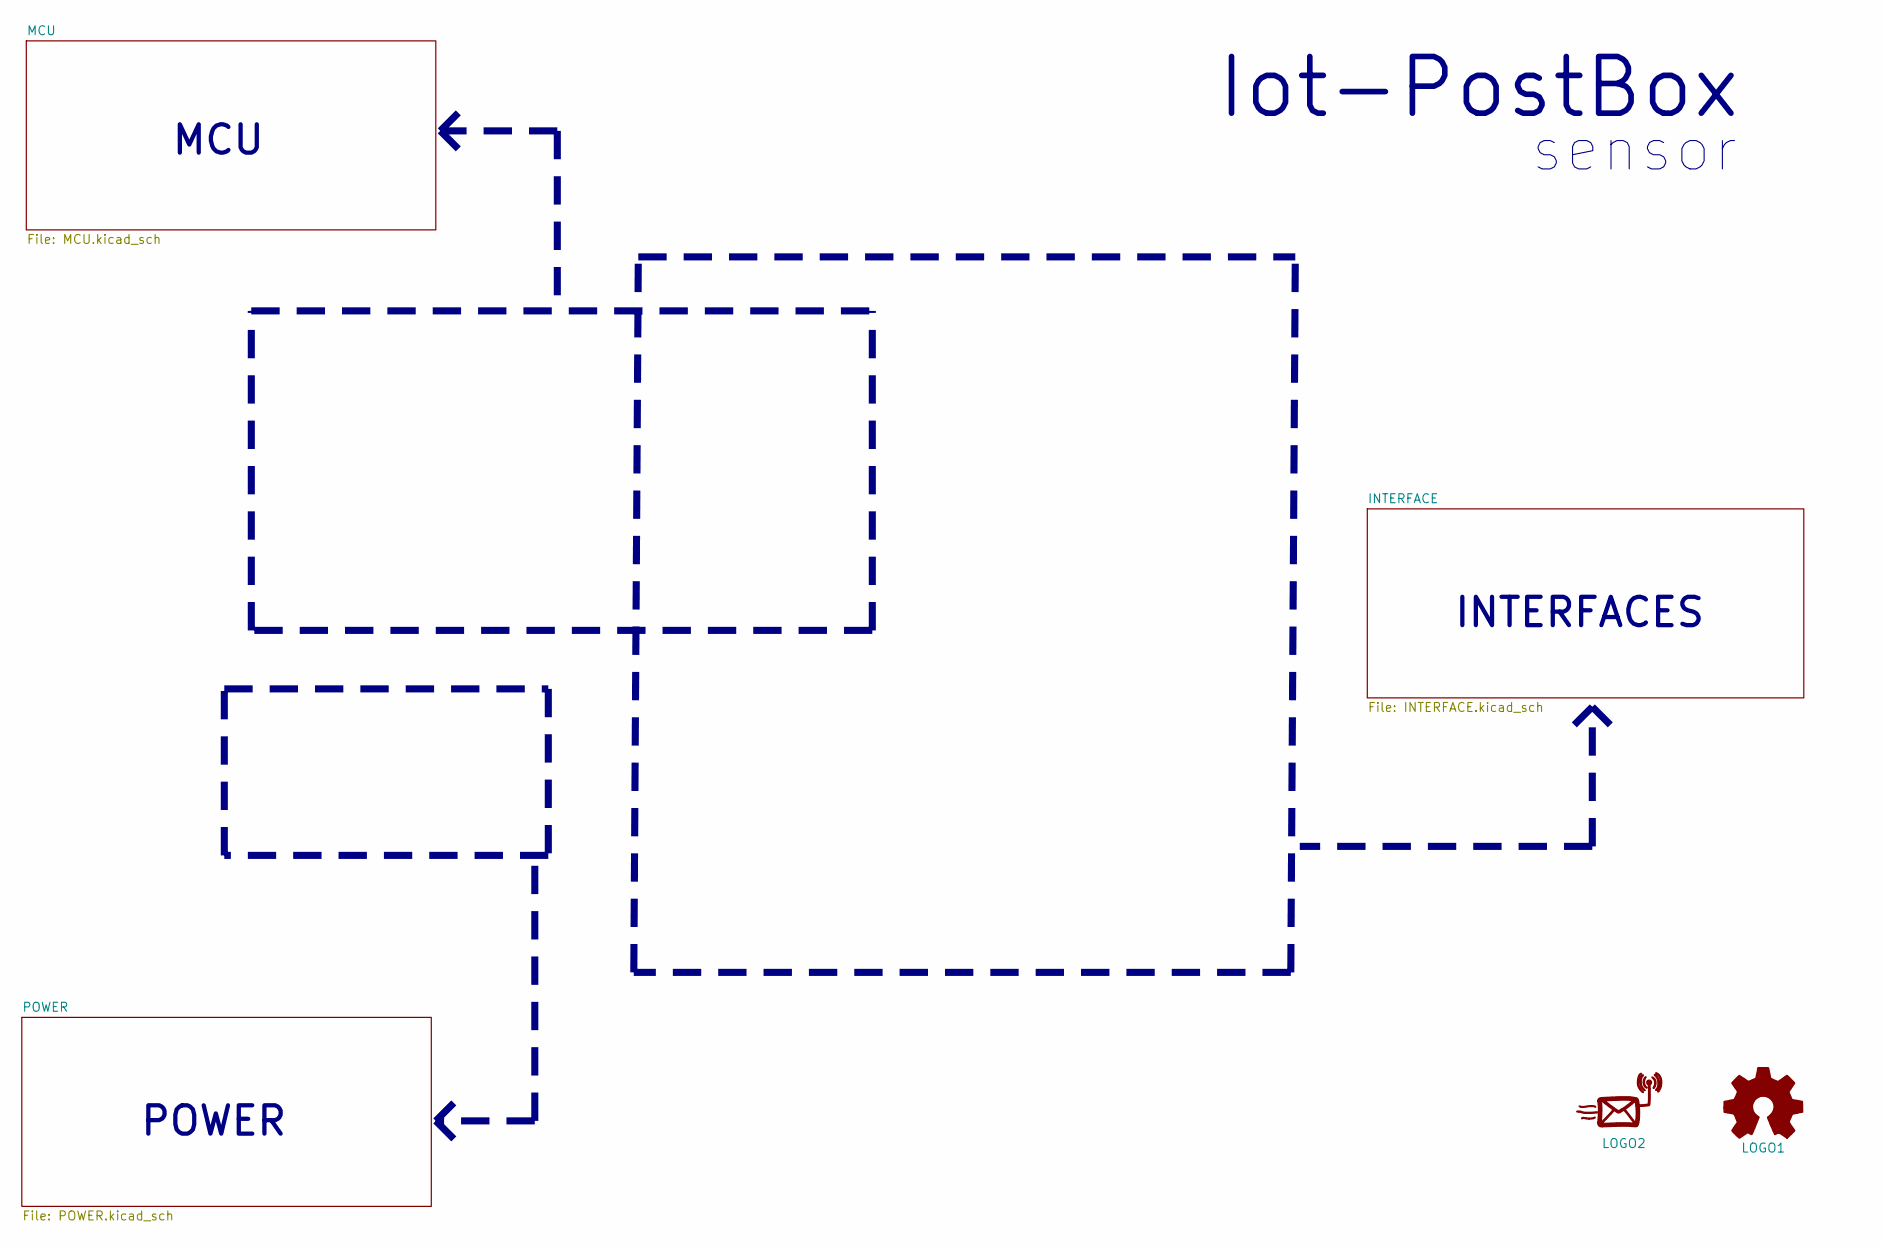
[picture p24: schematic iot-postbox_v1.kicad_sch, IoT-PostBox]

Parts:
LOGO1: Logo_Open_Hardware_Small; OSHW-Logo_5.7x6mm_SilkScreen
LOGO2: iot-postbox_logo

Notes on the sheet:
Iot-PostBox
POWER
INTERFACES
MCU
sensor

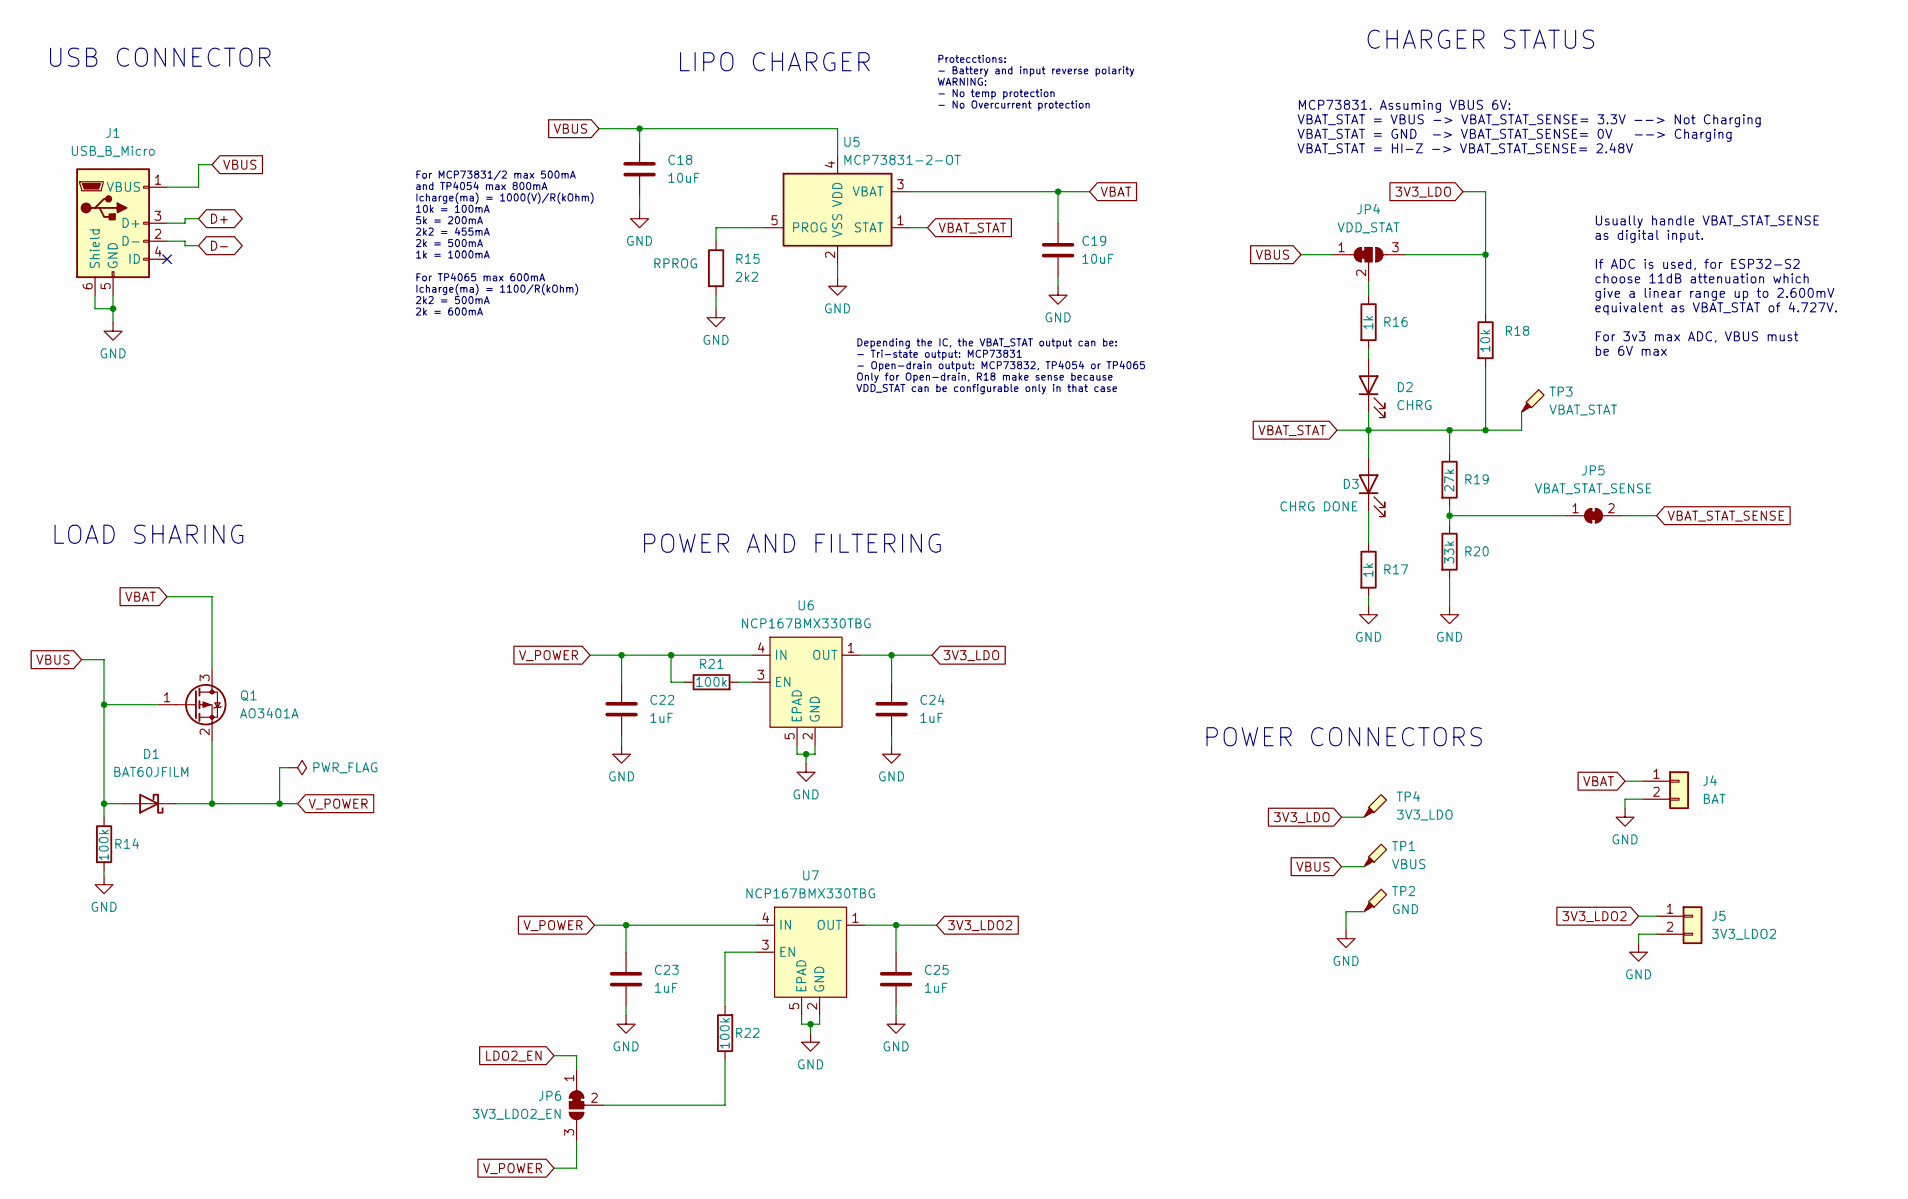
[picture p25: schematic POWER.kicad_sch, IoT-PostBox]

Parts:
C18, C19: 10uF; C_1206_3216Metric; Mouser CL31A106KAHNNNF
C22, C23, C24, C25: 1uF; C_0603_1608Metric; Mouser CL10A105KA8NNNC
D1: BAT60JFILM; D_SOD-323; LCSC C133103
D2: CHRG; LED_0805_2012Metric
D3: CHRG DONE; LED_0805_2012Metric
J1: USB_B_Micro; USB_Micro-B_Amphenol_10118194_Horizontal
J4: BAT; PinHeader_1x02_P2.54mm_Vertical
J5: 3V3_LDO2; PinHeader_1x02_P2.54mm_Vertical
JP4: VDD_STAT; SolderJumper-3_P1.3mm_Bridged12_RoundedPad1.0x1.5mm_NumberL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
JP5: VBAT_STAT_SENSE; SolderJumper-2_P1.3mm_Bridged_RoundedPad1.0x1.5mm
JP6: 3V3_LDO2_EN; SolderJumper-3_P1.3mm_Bridged12_RoundedPad1.0x1.5mm_NumberL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
Q1: AO3401A; SOT-23; LCSC C2836398
R14: 100k; R_0805_2012Metric; Mouser RC0805FR-07100KL
R15: 2k2; R_0805_2012Metric; Mouser CR0805-JW-222ELF
R16, R17: 1k; R_0805_2012Metric; Mouser AC0805FR-071KL
R18: 10k; R_0805_2012Metric; Mouser AC0805JR-0710KL
R19: 27k; R_0805_2012Metric; Mouser RC0805FR-1327KL
R20: 33k; R_0805_2012Metric; Mouser RC0805FR-0733KL
R21, R22: 100k; R_0603_1608Metric; Mouser RK73B1JTTD104J
TP1: VBUS; TestPoint_Pad_D2.5mm
TP2: GND; TestPoint_Pad_D2.5mm
TP3: VBAT_STAT; TestPoint_Pad_D2.0mm
TP4: 3V3_LDO; TestPoint_Pad_D2.0mm
U5: MCP73831-2-OT; SOT-23-5; Mouser MCP73831T-2ACI/OT
U6, U7: NCP167BMX330TBG; NCP167BMX330TBG_XDFN4; Mouser NCP167BMX330TBG

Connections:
3V3_LDO: C24.1, JP4.3 (B), R18.1, TP4.1, U6.1 (OUT); also elsewhere on the board
3V3_LDO2: C25.1, J5.1, U7.1 (OUT); also elsewhere on the board
D+: J1.3 (D+); also elsewhere on the board
D-: J1.2 (D-); also elsewhere on the board
GND: C18.2, C19.2, C22.2, C23.2, C24.2, C25.2, J1.5 (GND), J1.6 (Shield), J4.2, J5.2, R14.2, R15.2, R17.2, R20.2, TP2.1, U5.2 (VSS), U6.2 (GND), U6.5 (EPAD), U7.2 (GND), U7.5 (EPAD); also elsewhere on the board
LDO2_EN: JP6.1 (A); also elsewhere on the board
unnamed: D2.2 (A), R16.2
unnamed: D3.1 (K), R17.1
unnamed: JP4.2 (C), R16.1
unnamed: JP5.1 (A), R19.2, R20.1
unnamed: JP6.2 (C), R22.1
unnamed: R15.1, U5.5 (PROG)
unnamed: R21.2, U6.3 (EN)
unnamed: R22.2, U7.3 (EN)
VBAT: C19.1, J4.1, Q1.3 (D), U5.3 (VBAT); also elsewhere on the board
VBAT_STAT: D2.1 (K), D3.2 (A), R18.2, R19.1, TP3.1, U5.1 (STAT)
VBAT_STAT_SENSE: JP5.2 (B); also elsewhere on the board
VBUS: C18.1, D1.2 (A), J1.1 (VBUS), JP4.1 (A), Q1.1 (G), R14.1, TP1.1, U5.4 (VDD); also elsewhere on the board
V_POWER: C22.1, C23.1, D1.1 (K), JP6.3 (B), Q1.2 (S), R21.1, U6.4 (IN), U7.4 (IN); also elsewhere on the board

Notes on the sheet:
LOAD SHARING
POWER CONNECTORS
Usually handle VBAT_STAT_SENSE as digital input. If ADC is used, for ESP32-S2 choose 11dB attenuation which give a linear range up to 2.600mV equivalent as VBAT_STAT of 4.727V. For 3v3 max ADC, VBUS must be 6V max
For MCP73831/2 max 500mA and TP4054 max 800mA Icharge(ma) = 1000(V)/R(kOhm) 10k = 100mA 5k = 200mA 2k2 = 455mA 2k = 500mA 1k = 1000mA For TP4065 max 600mA Icharge(ma) = 1100/R(kOhm) 2k2 = 500mA 2k = 600mA
POWER AND FILTERING
CHARGER STATUS
Depending the IC, the VBAT_STAT output can be: - Tri-state output: MCP73831 - Open-drain output: MCP73832, TP4054 or TP4065 Only for Open-drain, R18 make sense because VDD_STAT can be configurable only in that case
LIPO CHARGER
Protecctions: - Battery and input reverse polarity WARNING: - No temp protection - No Overcurrent protection
MCP73831. Assuming VBUS 6V: VBAT_STAT = VBUS -> VBAT_STAT_SENSE= 3.3V --> Not Charging VBAT_STAT = GND -> VBAT_STAT_SENSE= 0V --> Charging VBAT_STAT = HI-Z -> VBAT_STAT_SENSE= 2.48V
USB CONNECTOR

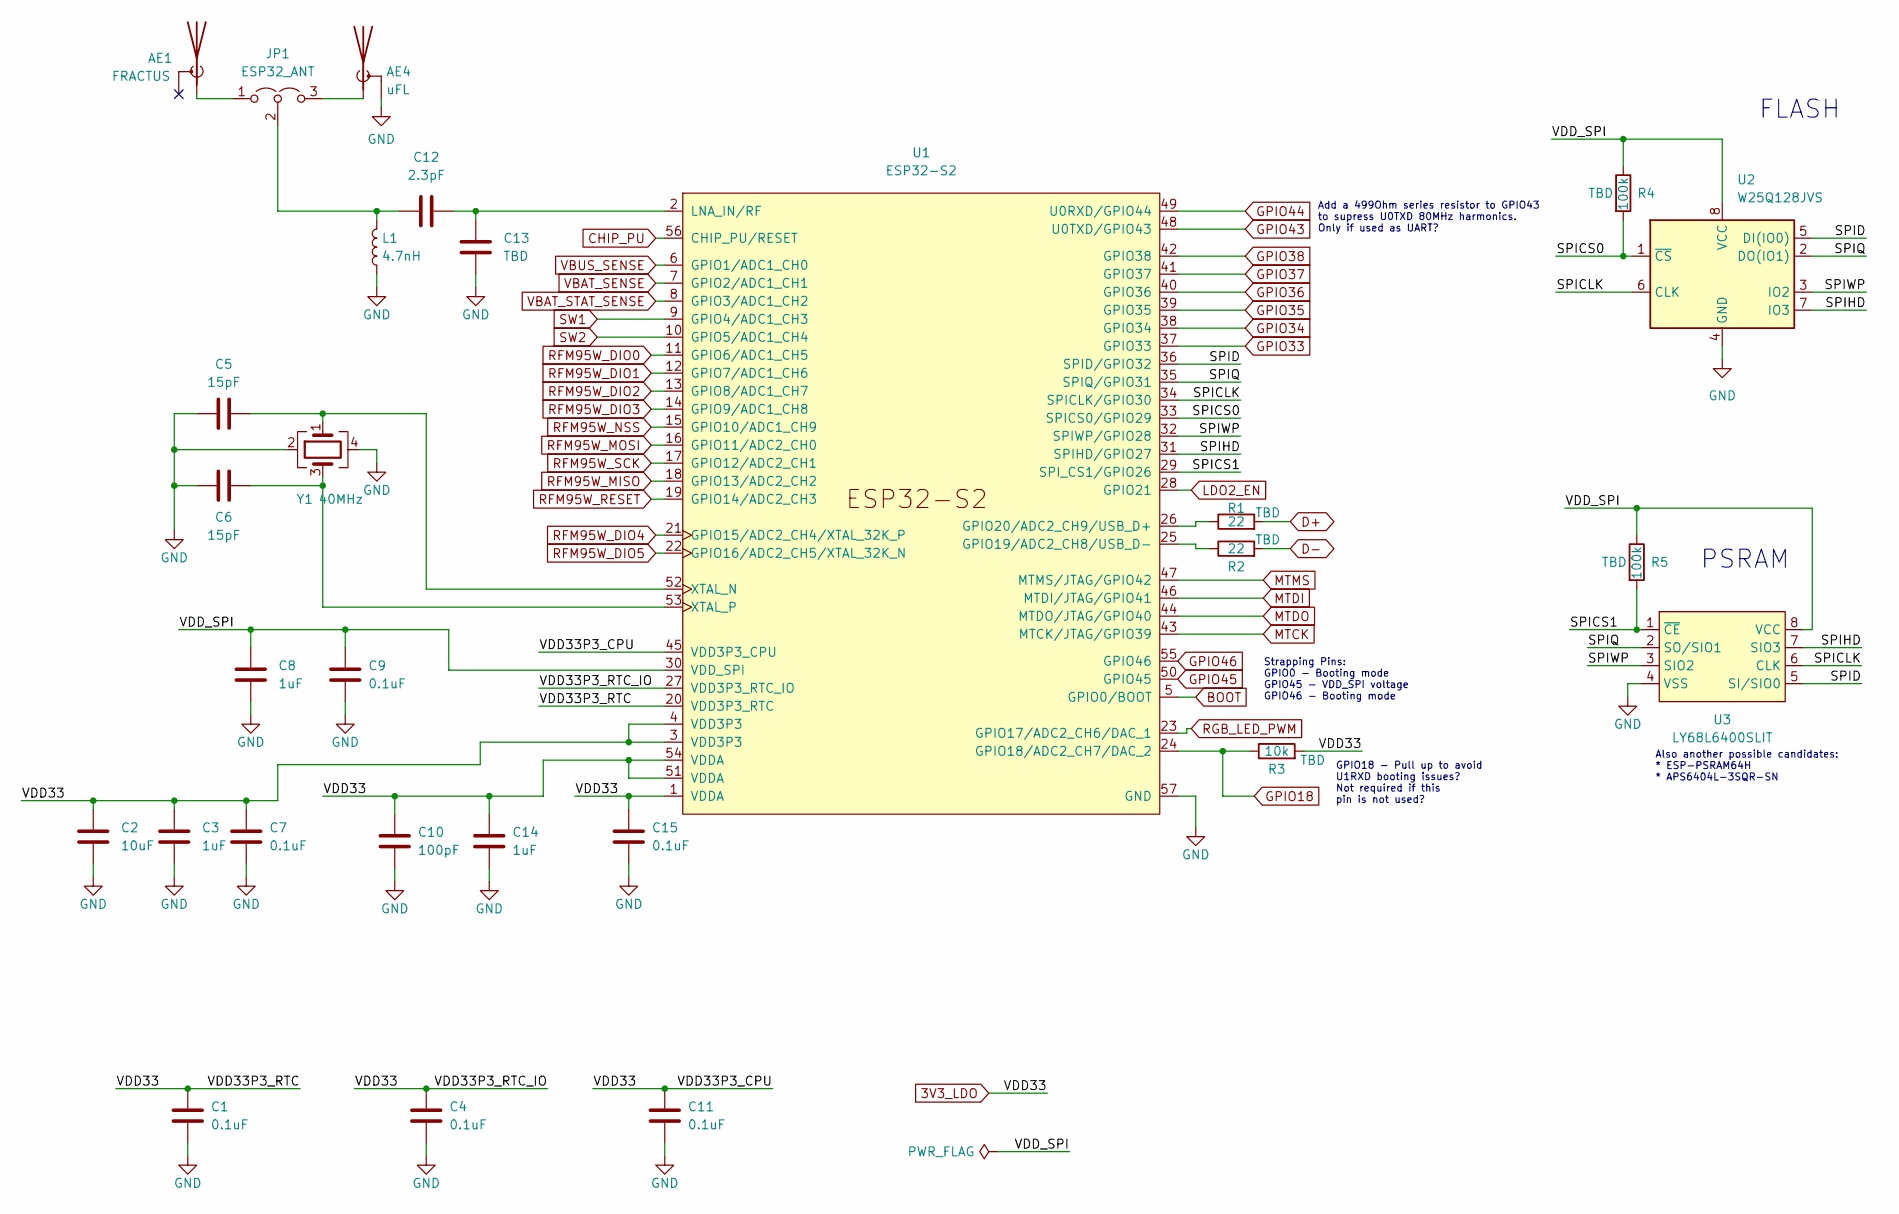
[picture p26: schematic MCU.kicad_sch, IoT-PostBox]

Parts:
AE1: FRACTUS; NN01-102; Mouser NN01-102
AE4: uFL; U.FL_Molex_MCRF_73412-0110_Vertical; Mouser RECE.20279.001E.01
C1, C4, C7, C9, C11, C15: 0.1uF; C_0603_1608Metric; Mouser CL10B104KB8NNWC
C2: 10uF; C_1206_3216Metric; Mouser CL31A106KAHNNNF
C3, C8, C14: 1uF; C_0805_2012Metric; Mouser EMK212BJ105KG-T
C5, C6: 15pF; C_0603_1608Metric; Mouser 06035A150JAT2A
C10: 100pF; C_0603_1608Metric; Mouser GRM1885C1H101JA01D
C12: 2.3pF; C_0402_1005Metric; Mouser GRM1555C2A2R3CA01J
C13: TBD; C_0402_1005Metric; Mouser AC0402JR-130RL
JP1: ESP32_ANT; Jumper_0402_x3; Mouser AC0402JR-130RL
L1: 4.7nH; L_0402_1005Metric; Mouser LCCI0402S4N7GTAR or shielded 7447840047G
R1, R2: 22; R_0603_1608Metric; Mouser RC0603FR-1022RL
R3: 10k; R_0603_1608Metric; Mouser RC0603JR-0710KL
R4, R5: 100k; R_0603_1608Metric; Mouser RK73B1JTTD104J
U1: ESP32-S2; ESP32_S2_QFN56; Mouser ESP32-S2
U2: W25Q128JVS; SOIC-8_5.23x5.23mm_P1.27mm; Mouser W25Q128JVSIM TR
U3: LY68L6400SLIT; SOP-8_3.9x4.9mm_P1.27mm; LCSC C261881
Y1: 40MHz; ECS-400-10-37B2-CKM-TR; Mouser ECS-400-10-37B2-CKM

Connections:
3V3_LDO: C1.1, C2.1, C3.1, C4.1, C7.1, C10.1, C11.1, C14.1, C15.1, R3.2, U1.1 (VDDA), U1.3 (VDD3P3), U1.4 (VDD3P3), U1.20 (VDD3P3_RTC), U1.27 (VDD3P3_RTC_IO), U1.45 (VDD3P3_CPU), U1.51 (VDDA), U1.54 (VDDA); also elsewhere on the board
/MCU/SPICLK: U1.34 (SPICLK/GPIO30), U2.6 (CLK), U3.6 (CLK)
/MCU/SPICS0: R4.2, U1.33 (SPICS0/GPIO29), U2.1 (~CS)
/MCU/SPICS1: R5.2, U1.29 (SPI_CS1/GPIO26), U3.1 (~CE)
/MCU/SPID: U1.36 (SPID/GPIO32), U2.5 (DI(IO0)), U3.5 (SI/SIO0)
/MCU/SPIHD: U1.31 (SPIHD/GPIO27), U2.7 (IO3), U3.7 (SIO3)
/MCU/SPIQ: U1.35 (SPIQ/GPIO31), U2.2 (DO(IO1)), U3.2 (SO/SIO1)
/MCU/SPIWP: U1.32 (SPIWP/GPIO28), U2.3 (IO2), U3.3 (SIO2)
/MCU/VDD_SPI: C8.1, C9.1, R4.1, R5.1, U1.30 (VDD_SPI), U2.8 (VCC), U3.8 (VCC)
BOOT: U1.5 (GPIO0/BOOT); also elsewhere on the board
CHIP_PU: U1.56 (CHIP_PU/RESET); also elsewhere on the board
D+: R1.2; also elsewhere on the board
D-: R2.2; also elsewhere on the board
GND: AE4.2 (Shield), C1.2, C2.2, C3.2, C4.2, C5.1, C6.1, C7.2, C8.2, C9.2, C10.2, C11.2, C13.2, C14.2, C15.2, L1.1, U1.57 (GND), U2.4 (GND), U3.4 (VSS), Y1.2, Y1.4; also elsewhere on the board
GPIO18: R3.1, U1.24 (GPIO18/ADC2_CH7/DAC_2)
GPIO33: U1.37 (GPIO33); also elsewhere on the board
GPIO34: U1.38 (GPIO34); also elsewhere on the board
GPIO35: U1.39 (GPIO35); also elsewhere on the board
GPIO36: U1.40 (GPIO36); also elsewhere on the board
GPIO37: U1.41 (GPIO37); also elsewhere on the board
GPIO38: U1.42 (GPIO38); also elsewhere on the board
GPIO43: U1.48 (U0TXD/GPIO43); also elsewhere on the board
GPIO44: U1.49 (U0RXD/GPIO44); also elsewhere on the board
GPIO45: U1.50 (GPIO45); also elsewhere on the board
GPIO46: U1.55 (GPIO46); also elsewhere on the board
LDO2_EN: U1.28 (GPIO21); also elsewhere on the board
MTCK: U1.43 (MTCK/JTAG/GPIO39); also elsewhere on the board
MTDI: U1.46 (MTDI/JTAG/GPIO41); also elsewhere on the board
MTDO: U1.44 (MTDO/JTAG/GPIO40); also elsewhere on the board
MTMS: U1.47 (MTMS/JTAG/GPIO42); also elsewhere on the board
unnamed: AE1.1 (A), JP1.1 (A)
unnamed: AE4.1 (A), JP1.3 (B)
unnamed: C12.1, JP1.2 (C), L1.2
unnamed: R2.1, U1.25 (GPIO19/ADC2_CH8/USB_D-)
unnamed: R1.1, U1.26 (GPIO20/ADC2_CH9/USB_D+)
unnamed: C12.2, C13.1, U1.2 (LNA_IN/RF)
unnamed: C5.2, U1.52 (XTAL_N), Y1.1
unnamed: C6.2, U1.53 (XTAL_P), Y1.3
RFM95W_DIO0: U1.11 (GPIO6/ADC1_CH5); also elsewhere on the board
RFM95W_DIO1: U1.12 (GPIO7/ADC1_CH6); also elsewhere on the board
RFM95W_DIO2: U1.13 (GPIO8/ADC1_CH7); also elsewhere on the board
RFM95W_DIO3: U1.14 (GPIO9/ADC1_CH8); also elsewhere on the board
RFM95W_DIO4: U1.21 (GPIO15/ADC2_CH4/XTAL_32K_P); also elsewhere on the board
RFM95W_DIO5: U1.22 (GPIO16/ADC2_CH5/XTAL_32K_N); also elsewhere on the board
RFM95W_MISO: U1.18 (GPIO13/ADC2_CH2); also elsewhere on the board
RFM95W_MOSI: U1.16 (GPIO11/ADC2_CH0); also elsewhere on the board
RFM95W_NSS: U1.15 (GPIO10/ADC1_CH9); also elsewhere on the board
RFM95W_RESET: U1.19 (GPIO14/ADC2_CH3); also elsewhere on the board
RFM95W_SCK: U1.17 (GPIO12/ADC2_CH1); also elsewhere on the board
RGB_LED_PWM: U1.23 (GPIO17/ADC2_CH6/DAC_1); also elsewhere on the board
SW1: U1.9 (GPIO4/ADC1_CH3); also elsewhere on the board
SW2: U1.10 (GPIO5/ADC1_CH4); also elsewhere on the board
VBAT_SENSE: U1.7 (GPIO2/ADC1_CH1); also elsewhere on the board
VBAT_STAT_SENSE: U1.8 (GPIO3/ADC1_CH2); also elsewhere on the board
VBUS_SENSE: U1.6 (GPIO1/ADC1_CH0); also elsewhere on the board

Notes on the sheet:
Also another possible candidates: * ESP-PSRAM64H * APS6404L-3SQR-SN
PSRAM
Add a 499Ohm series resistor to GPIO43 to supress U0TXD 80MHz harmonics. Only if used as UART?
GPIO18 - Pull up to avoid U1RXD booting issues? Not required if this pin is not used?
Strapping Pins: GPIO0 - Booting mode GPIO45 - VDD_SPI voltage GPIO46 - Booting mode
FLASH

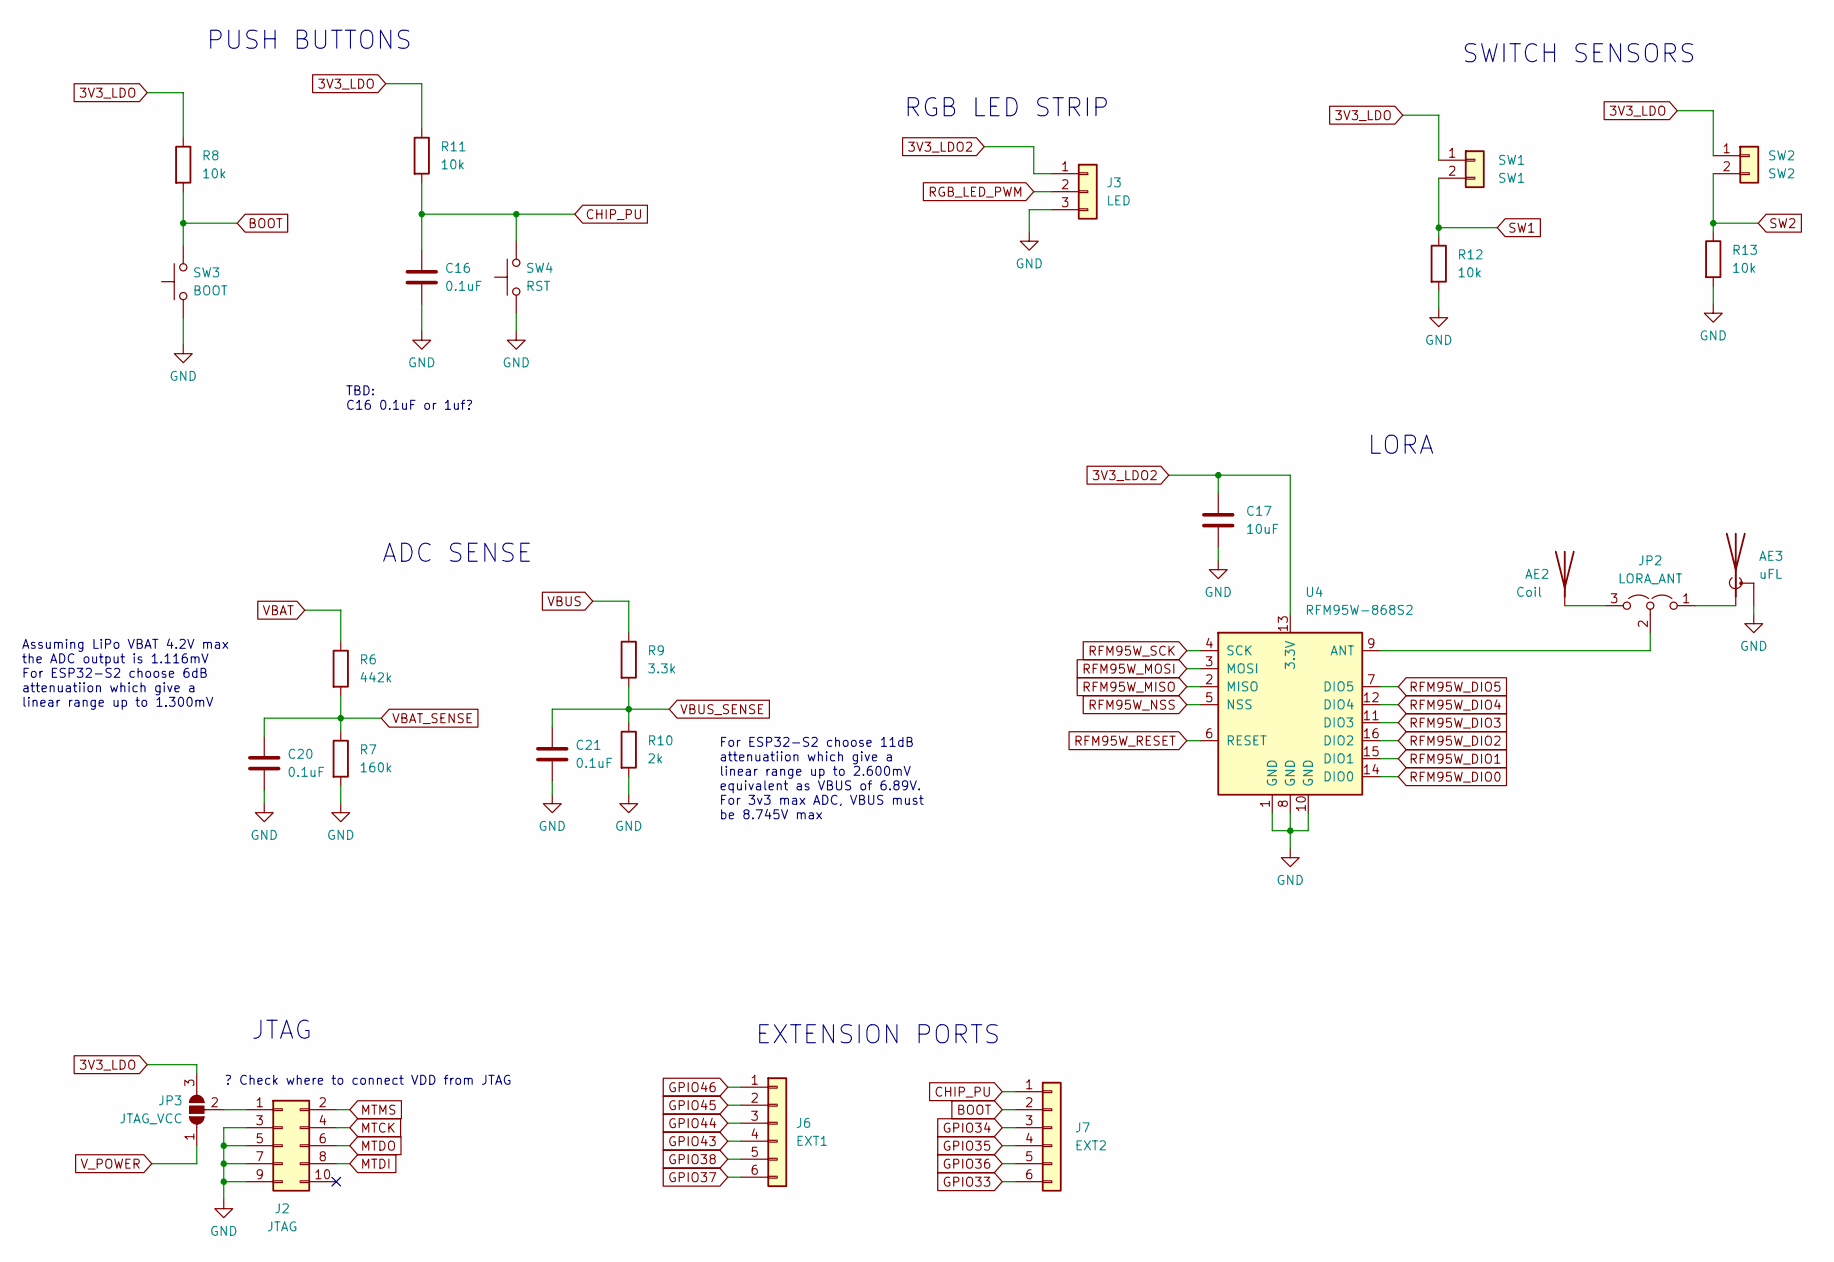
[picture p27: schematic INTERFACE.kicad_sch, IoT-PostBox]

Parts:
AE2: Coil; 868Mhz_sprin_antenna_SW868-TH13; LCSC T3-868M or VG868SNX18-5W2
AE3: uFL; U.FL_Molex_MCRF_73412-0110_Vertical; Mouser RECE.20279.001E.01
C16, C20, C21: 0.1uF; C_0603_1608Metric; Mouser CL10B104KB8NNWC
C17: 10uF; C_1206_3216Metric; Mouser CL31A106KAHNNNF
J2: JTAG; PinHeader_2x05_P2.54mm_Vertical_SMD; LCSC C124391
J3: LED; PinHeader_1x03_P2.54mm_Vertical
J6: EXT1; PinHeader_1x06_P2.54mm_Vertical
J7: EXT2; PinHeader_1x06_P2.54mm_Vertical
JP2: LORA_ANT; Jumper_0402_x3; Mouser AC0402JR-130RL
JP3: JTAG_VCC; SolderJumper-3_P2.0mm_Open_TrianglePad1.0x1.5mm_NumberLabels
R6: 442k; R_0805_2012Metric; Mouser RC0805FR-07442KL
R7: 160k; R_0805_2012Metric; Mouser CR0805-FX-1603ELF
R8, R11, R12, R13: 10k; R_0603_1608Metric; Mouser RC0603JR-0710KL
R9: 3.3k; R_0805_2012Metric; Mouser RC0805FR-133K3L
R10: 2k; R_0805_2012Metric; Mouser RT0805FRE072KL
SW1: SW1; PinHeader_1x02_P2.54mm_Vertical
SW2: SW2; PinHeader_1x02_P2.54mm_Vertical
SW3: BOOT; SW_Push_SPST_NO_Alps_SKRK; LCSC C843669
SW4: RST; SW_Push_SPST_NO_Alps_SKRK; LCSC C843669
U4: RFM95W-868S2; HOPERF_RFM9XW_SMD; LCSC C2844472

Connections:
3V3_LDO: JP3.3 (B), R8.1, R11.1, SW1.1, SW2.1; also elsewhere on the board
3V3_LDO2: C17.1, J3.1, U4.13 (3.3V); also elsewhere on the board
BOOT: J7.2, R8.2, SW3.2; also elsewhere on the board
CHIP_PU: C16.1, J7.1, R11.2, SW4.2; also elsewhere on the board
GND: AE3.2 (Shield), C16.2, C17.2, C20.2, C21.2, J2.3, J2.5, J2.7, J2.9, J3.3, R7.2, R10.2, R12.2, R13.2, SW3.1, SW4.1, U4.1 (GND), U4.8 (GND), U4.10 (GND); also elsewhere on the board
GPIO33: J7.6; also elsewhere on the board
GPIO34: J7.3; also elsewhere on the board
GPIO35: J7.4; also elsewhere on the board
GPIO36: J7.5; also elsewhere on the board
GPIO37: J6.6; also elsewhere on the board
GPIO38: J6.5; also elsewhere on the board
GPIO43: J6.4; also elsewhere on the board
GPIO44: J6.3; also elsewhere on the board
GPIO45: J6.2; also elsewhere on the board
GPIO46: J6.1; also elsewhere on the board
MTCK: J2.4; also elsewhere on the board
MTDI: J2.8; also elsewhere on the board
MTDO: J2.6; also elsewhere on the board
MTMS: J2.2; also elsewhere on the board
unnamed: AE2.1 (A), JP2.3 (B)
unnamed: AE3.1 (A), JP2.1 (A)
unnamed: J2.1, JP3.2 (C)
unnamed: JP2.2 (C), U4.9 (ANT)
RFM95W_DIO0: U4.14 (DIO0); also elsewhere on the board
RFM95W_DIO1: U4.15 (DIO1); also elsewhere on the board
RFM95W_DIO2: U4.16 (DIO2); also elsewhere on the board
RFM95W_DIO3: U4.11 (DIO3); also elsewhere on the board
RFM95W_DIO4: U4.12 (DIO4); also elsewhere on the board
RFM95W_DIO5: U4.7 (DIO5); also elsewhere on the board
RFM95W_MISO: U4.2 (MISO); also elsewhere on the board
RFM95W_MOSI: U4.3 (MOSI); also elsewhere on the board
RFM95W_NSS: U4.5 (NSS); also elsewhere on the board
RFM95W_RESET: U4.6 (RESET); also elsewhere on the board
RFM95W_SCK: U4.4 (SCK); also elsewhere on the board
RGB_LED_PWM: J3.2; also elsewhere on the board
SW1: R12.1, SW1.2; also elsewhere on the board
SW2: R13.1, SW2.2; also elsewhere on the board
VBAT: R6.1; also elsewhere on the board
VBAT_SENSE: C20.1, R6.2, R7.1; also elsewhere on the board
VBUS: R9.1; also elsewhere on the board
VBUS_SENSE: C21.1, R9.2, R10.1; also elsewhere on the board
V_POWER: JP3.1 (A); also elsewhere on the board

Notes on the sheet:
RGB LED STRIP
PUSH BUTTONS
TBD: C16 0.1uF or 1uf?
? Check where to connect VDD from JTAG
SWITCH SENSORS
Assuming LiPo VBAT 4.2V max the ADC output is 1.116mV For ESP32-S2 choose 6dB attenuatiion which give a linear range up to 1.300mV
LORA
For ESP32-S2 choose 11dB attenuatiion which give a linear range up to 2.600mV equivalent as VBUS of 6.89V. For 3v3 max ADC, VBUS must be 8.745V max
ADC SENSE
EXTENSION PORTS
JTAG

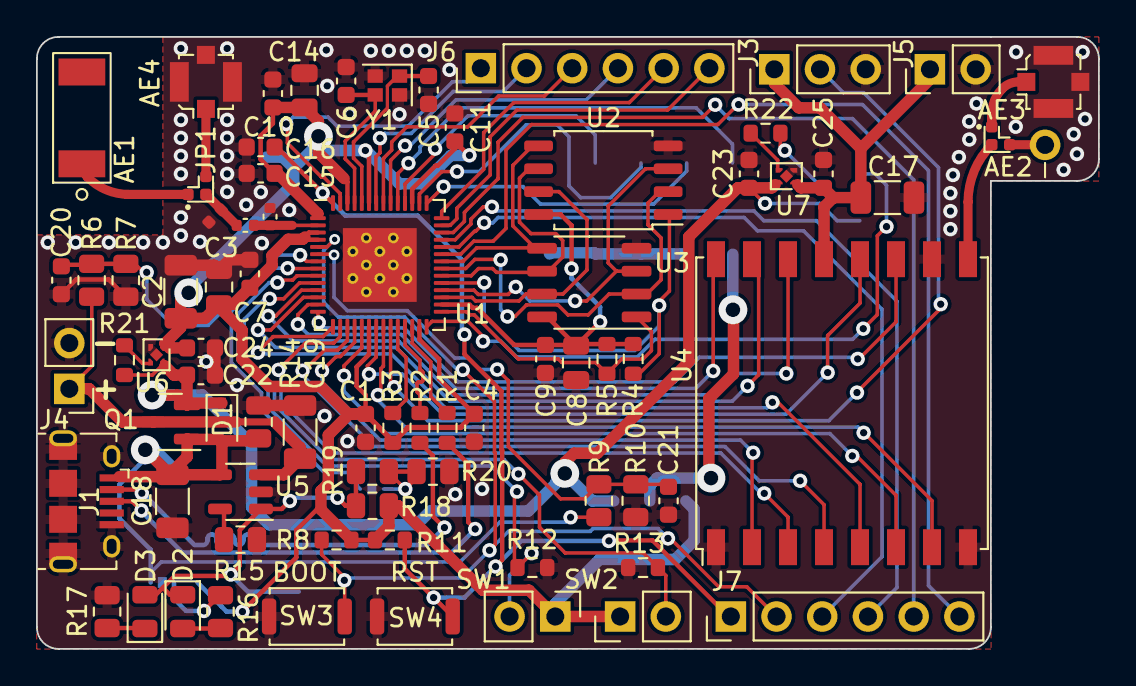
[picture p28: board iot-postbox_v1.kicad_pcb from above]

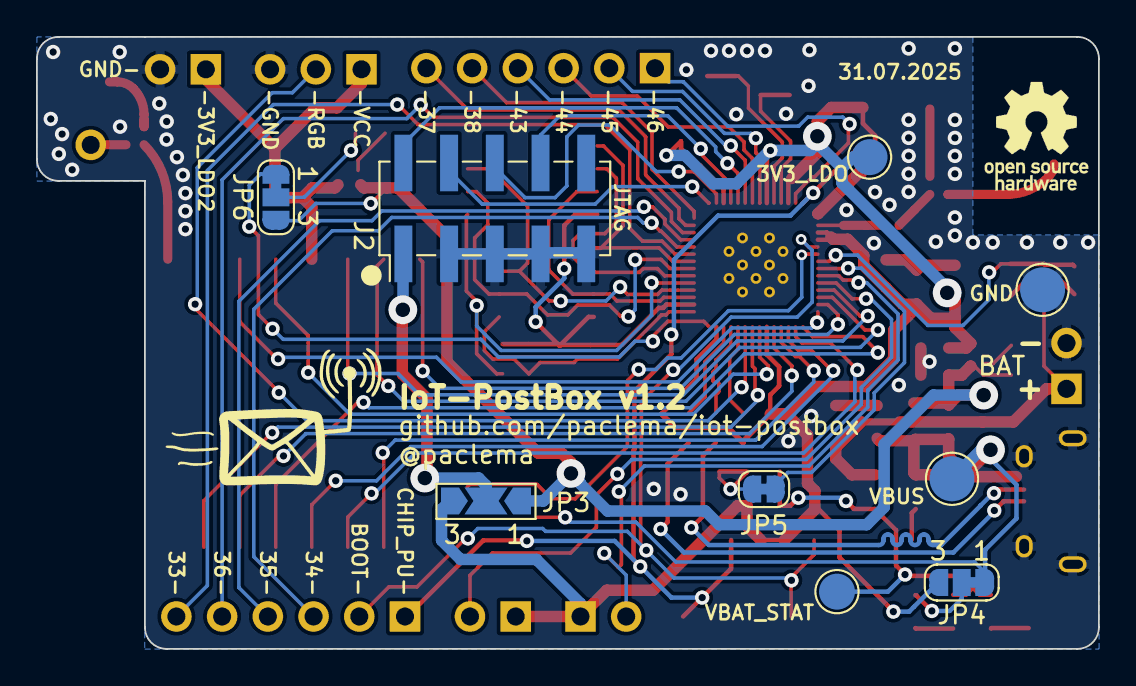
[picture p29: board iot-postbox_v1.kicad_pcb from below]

Board: 2 copper layers, 59.0 x 34.0 mm, 87 parts (11 on the bottom side), 72 nets.

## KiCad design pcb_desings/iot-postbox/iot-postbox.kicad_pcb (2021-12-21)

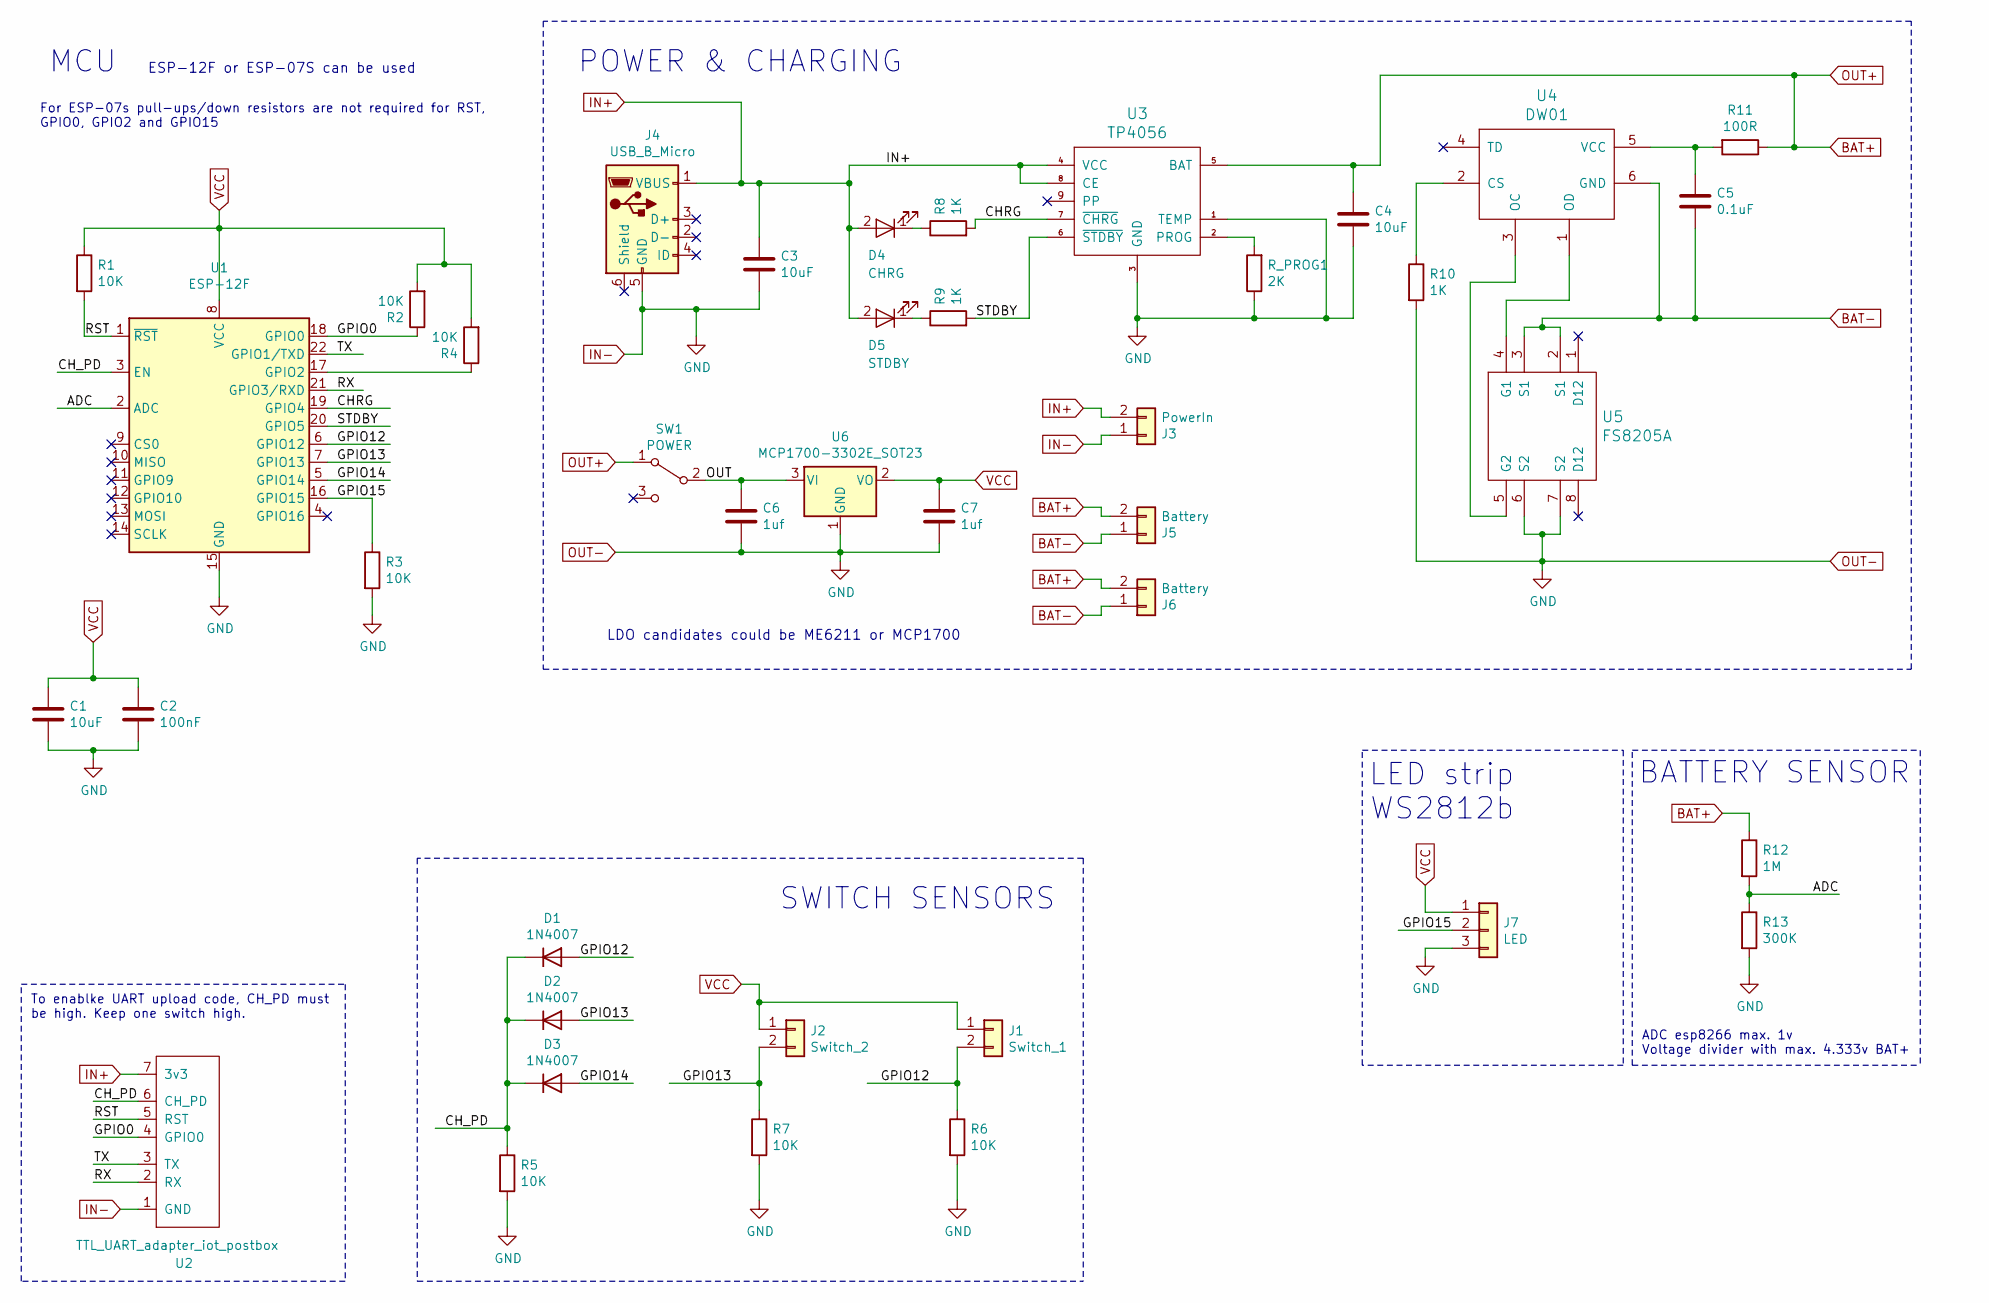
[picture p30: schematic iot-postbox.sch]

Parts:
C1, C3, C4: 10uF; C_0805_2012Metric
C2: 100nF; C_0805_2012Metric
C5: 0.1uF; C_0805_2012Metric
C6, C7: 1uf; C_0805_2012Metric
D1, D2, D3: 1N4007; D_SOD-123
D4: CHRG; LED_0805_2012Metric
D5: STDBY; LED_0805_2012Metric
J1: Switch_1; PinHeader_1x02_P2.54mm_Vertical
J2: Switch_2; PinHeader_1x02_P2.54mm_Vertical
J3: PowerIn; PinHeader_1x02_P2.54mm_Vertical
J4: USB_B_Micro; USB_Micro-B_Amphenol_10118194_Horizontal
J5: Battery; JST_PH_S2B-PH-SM4-TB_1x02-1MP_P2.00mm_Horizontal
J6: Battery; PinHeader_1x02_P2.54mm_Vertical
J7: LED; PinHeader_1x03_P2.54mm_Vertical
R1, R2, R3, R4, R5, R6, R7: 10K; R_0805_2012Metric
R8, R9, R10: 1K; R_0805_2012Metric
R11: 100R; R_0805_2012Metric
R12: 1M; R_0805_2012Metric
R13: 300K; R_0805_2012Metric
R_PROG1: 2K; R_0805_2012Metric
SW1: POWER; 1P2T_SPDT_MSK-C02_7pin
U1: ESP-12F; ESP-12E
U2: TTL_UART_adapter_iot_postbox; PinHeader_1x07_P2.54mm_Vertical
U3: TP4056; TP4056_SOP-8-PP
U4: DW01; SOT-23-6_Handsoldering
U5: FS8205A; TSSOP-8_4.4x3mm_P0.65mm
U6: MCP1700-3302E_SOT23; SOT-23

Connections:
/ADC: R12.2, R13.1, U1.2 (ADC)
/CHRG: R8.2, U1.19 (GPIO4), U3.7 (~CHRG)
/CH_PD: D1.1 (K), D2.1 (K), D3.1 (K), R5.1, U1.3 (EN), U2.6 (CH_PD)
/GPIO0: R2.1, U1.18 (GPIO0), U2.4 (GPIO0)
/GPIO12: D1.2 (A), J1.2, R6.1, U1.6 (GPIO12)
/GPIO13: D2.2 (A), J2.2, R7.1, U1.7 (GPIO13)
/GPIO14: D3.2 (A), U1.5 (GPIO14)
/GPIO15: J7.2, R3.1, U1.16 (GPIO15)
/OUT: C6.1, SW1.2 (B), U6.3 (VI)
/RST: R1.2, U1.1 (~RST), U2.5 (RST)
/RX: U1.21 (GPIO3/RXD), U2.2 (RX)
/STDBY: R9.2, U1.20 (GPIO5), U3.6 (~STDBY)
/TX: U1.22 (GPIO1/TXD), U2.3 (TX)
BAT+: C4.1, J5.2, J6.2, R11.1, R12.1, SW1.1 (A), U3.5 (BAT)
BAT-: C5.2, J5.1, J6.1, U4.6 (GND), U5.2 (S1), U5.3 (S1)
IN+: C3.1, D4.2 (A), D5.2 (A), J3.2, J4.1 (VBUS), U2.7 (3v3), U3.4 (VCC), U3.8 (CE)
IN-: C1.2, C2.2, C3.2, C4.2, C6.2, C7.2, J3.1, J4.5 (GND), J7.3, R3.2, R5.2, R6.2, R7.2, R10.2, R13.2, R_PROG1.1, U1.15 (GND), U2.1 (GND), U3.1 (TEMP), U3.3 (GND), U5.6 (S2), U5.7 (S2), U6.1 (GND)
unnamed: C5.1, R11.2, U4.5 (VCC)
unnamed: D4.1 (K), R8.1
unnamed: D5.1 (K), R9.1
unnamed: R4.1, U1.17 (GPIO2)
unnamed: R10.1, U4.2 (CS)
unnamed: R_PROG1.2, U3.2 (PROG)
unnamed: U4.1 (OD), U5.4 (G1)
unnamed: U4.3 (OC), U5.5 (G2)
VCC: C1.1, C2.1, C7.1, J1.1, J2.1, J7.1, R1.1, R2.2, R4.2, U1.8 (VCC), U6.2 (VO)

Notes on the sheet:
To enablke UART upload code, CH_PD must be high. Keep one switch high.
POWER & CHARGING
SWITCH SENSORS
MCU
ESP-12F or ESP-07S can be used
LDO candidates could be ME6211 or MCP1700
ADC esp8266 max. 1v Voltage divider with max. 4.333v BAT+
BATTERY SENSOR
For ESP-07s pull-ups/down resistors are not required for RST, GPIO0, GPIO2 and GPIO15
LED strip WS2812b

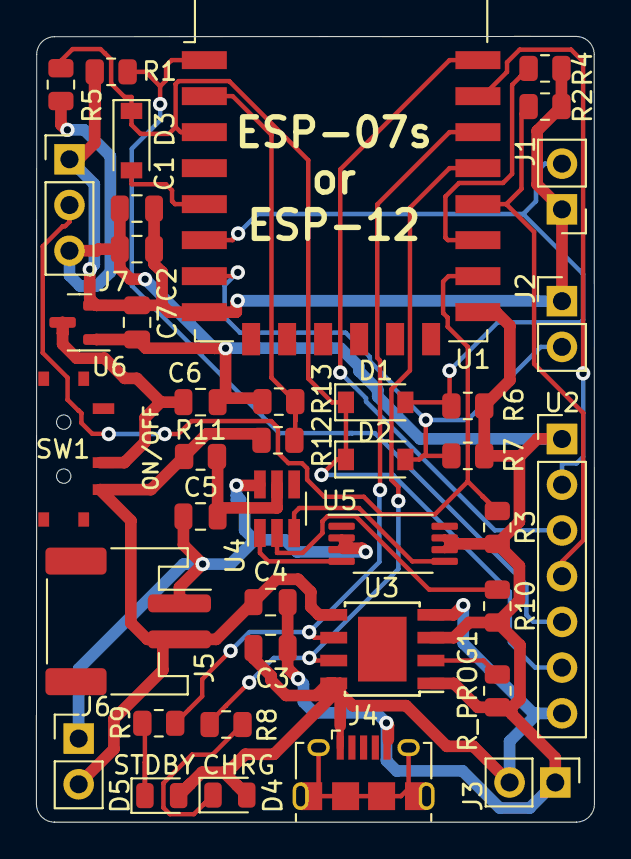
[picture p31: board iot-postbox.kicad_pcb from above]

Board: 2 copper layers, 31.0 x 43.6 mm, 40 parts (0 on the bottom side), 26 nets.

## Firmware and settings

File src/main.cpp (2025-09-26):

#include <Arduino.h>


// Main variables:
// #define DEBUG_ESP_CORE

// Enable wifi diagnostic using platformio build_glag: -D ENABLE_SERIAL_DEBUG:
#define ENABLE_SERIAL_DEBUG true


// Device configurations
unsigned long currentLoopMillis = 0;
unsigned long previousPublishMillis = 0;
unsigned long previousMainLoopMillis = 0;


// WebConfigServer Configuration
// -----------------------------
#include "WebConfigServer.h"
WebConfigServer config;   // <- global configuration object


#include <MQTTClient.h>
MQTTClient * mainClientMqtt;


// PostBox object
// ---------------------
#include "PostBox.h"
PostBox postbox;



void turnESPOff (void){

  postbox.powerOff();

  // digitalWrite(LDO2_EN_PIN, LOW);
  // Serial.println("CH_PD disabled");
  // delay(10);

  // //TODO: RUTINE FOR ESP32S2 
  // #ifndef ARDUINO_IOTPOSTBOX_V1
  //   digitalWrite(KEEP_WAKE_PIN, LOW); //Turns the ESP OFF
  // #endif
  // esp_wifi_stop();
  // delay(100);
  // esp_deep_sleep_start();

}

bool configuredSleep = false;

// Websocket functions to publish:
String getLoopTime(){ return String(currentLoopMillis - previousMainLoopMillis);}
String getRSSI(){ return String(WiFi.RSSI());}
String getHeapFree(){ return String((float)GET_FREE_HEAP/1000);}
String getVCC(){ return String((float)postbox.readVoltage(),3);}
String getVBat(){ return String((float)postbox.getVBat()/1000,4);}
String getVBatNow(){ return String((float)postbox.getVBatNow()/1000,3);}
String getVBus(){ return String((float)postbox.getVBus()/1000,3);}
String getVBatStat(){ return String(postbox.getVBatStat() ? "true" : "false");}
String getChargingStatus(){ return String((int)postbox.getChargingStatus());}
String getPowerStatus(){ return String((int)postbox.getPowerStatus());}
String getConfiguredSleep(){ return String(configuredSleep ? "true" : "false");}


void setup() {
  Serial.begin(115200);
  // while (!Serial);  // Wait until the Serial is available
  #ifdef ENABLE_SERIAL_DEBUG
    Serial.setDebugOutput(true);
  #endif


  postbox.setup();
  config.begin();

  config.setPreSleepRoutine(turnESPOff);
  
  
  mainClientMqtt = config.getMQTTClient();
  postbox.setMQTTClient(config.getMQTTClient());
  postbox.setMQTTBaseTopic(config.getDeviceTopic());
  postbox.init();
 
  config.addDashboardObject("heap_free", getHeapFree);
  config.addDashboardObject("loop", getLoopTime);
  config.addDashboardObject("RSSI", getRSSI);
  // config.addDashboardObject("VCC", getVCC);
  config.addDashboardObject("VBat", getVBat);
  // config.addDashboardObject("VBatNow", getVBatNow);
  config.addDashboardObject("VBus", getVBus);
  config.addDashboardObject("VBatStat", getVBatStat);
  config.addDashboardObject("ChargingStatus", getChargingStatus);
  config.addDashboardObject("PowerStatus", getPowerStatus);
  config.addDashboardObject("configuredSleep", getConfiguredSleep);


  Serial.println("###  Looping time\n");

}

void loop() {

  currentLoopMillis = millis();

  config.loop();

  postbox.loop();


  // Reconnection loop:
  // if (WiFi.status() != WL_CONNECTED) {
  //   config.begin();
  //   networkRestart();
  //   config.configureServer(&server);
  // }



  // TODO: clean defined process
  // #if defined(USE_TP4056) && defined(NO_SLEEP_WHILE_CHARGING)
    PowerStatus powerNow = postbox.getPowerStatus();
    if ( !postbox.isWakeUpPublished() || powerNow == PowerStatus::USBPowered || powerNow == PowerStatus::BatteryAndUSBPowered ){
      config.services.deep_sleep.enabled = false;
      // Serial.println("Deep sleep   ---> OFF");
      configuredSleep = false;
      } 
    else {
      config.services.deep_sleep.enabled = true;
      // Serial.println("Deep sleep   ---> ON");
      configuredSleep = true;
    }
    // TODO: save that deep sleep enabled within the config file instead hardcoding the variable
  // #else
    // if ( !wakeUpPublished ) config.services.deep_sleep.enabled = false;    
    // else config.services.deep_sleep.enabled = true; 
    // TODO: save that deep sleep enabled within the config file instead hardcoding the variable

  // #endif


  // Main Loop:
  if(mainClientMqtt->connected() && (config.device.publish_time_ms != 0) &&
      (currentLoopMillis - previousPublishMillis > (unsigned)config.device.publish_time_ms)) {
    previousPublishMillis = currentLoopMillis;
    // Here starts the MQTT publish loop configured:

    if (config.services.deep_sleep.enabled) {
      String topic = config.getDeviceTopic() + "sleepCountdown";
      String msg_pub ="{\"time_to_sleep\": ";
      msg_pub += String((config.services.deep_sleep.sleep_delay*1000 + config.getDeviceSetupTime() - (currentLoopMillis))/1000);
      msg_pub +=" }";
      mainClientMqtt->publish(topic.c_str(), msg_pub.c_str());
    }

    postbox.publishWakeUp("data");
  }
 
  previousMainLoopMillis = currentLoopMillis;
}

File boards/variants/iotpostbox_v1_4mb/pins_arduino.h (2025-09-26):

#ifndef Pins_Arduino_h
#define Pins_Arduino_h

#include <stdint.h>


#define USB_VID            0x303A
#define USB_PID            0x8104
#define USB_MANUFACTURER   "paclema"
#define USB_PRODUCT        "Iot-PostBox v1"
#define USB_SERIAL         "" // Empty string for MAC adddress


#define EXTERNAL_NUM_INTERRUPTS 46
#define NUM_DIGITAL_PINS        48
#define NUM_ANALOG_INPUTS       20

#define analogInputToDigitalPin(p)  (((p)<20)?(analogChannelToDigitalPin(p)):-1)
#define digitalPinToInterrupt(p)    (((p)<48)?(p):-1)
#define digitalPinHasPWM(p)         (p < 46)

// #define LED_BUILTIN     -1

#define LDO2_EN_PIN         21
#define PIN_NEOPIXEL        17
#define NEOPIXEL_NUM        1               // number of neopixels
#define NEOPIXEL_POWER      LDO2_EN_PIN     // power pin
#define NEOPIXEL_POWER_ON   HIGH            // power pin state when on
// #define I2C_POWER           7     // I2C power pin
// #define PIN_I2C_POWER       7     // I2C power pin

#define VBUS_SENSE_PIN			1
#define VBAT_SENSE_PIN			2
#define VBAT_STAT_SENSE_PIN		3

#define SW1_PIN		4
#define SW2_PIN		5

#define RFM95W_DIO0_PIN		6
#define RFM95W_DIO1_PIN		7
#define RFM95W_DIO2_PIN		8
#define RFM95W_DIO3_PIN		9
#define RFM95W_NSS_PIN		10
#define RFM95W_MOSI_PIN		11
#define RFM95W_SCK_PIN		12
#define RFM95W_MISO_PIN		13
#define RFM95W_RESET_PIN		14
#define RFM95W_DIO4_PIN		15
#define RFM95W_DIO5_PIN		16

static const uint8_t TX = 43;
static const uint8_t RX = 44;

static const uint8_t SDA = 33;
static const uint8_t SCL = 38;

static const uint8_t SS    = 34;
static const uint8_t MOSI  = 35;
static const uint8_t MISO  = 37;
static const uint8_t SCK   = 36;

static const uint8_t A0 = 1;
static const uint8_t A1 = 2;
static const uint8_t A2 = 3;
static const uint8_t A3 = 4;
static const uint8_t A4 = 5;
static const uint8_t A5 = 6;
static const uint8_t A6 = 7;
static const uint8_t A7 = 8;
static const uint8_t A8 = 9;
static const uint8_t A9 = 10;
static const uint8_t A10 = 11;
static const uint8_t A11 = 12;
static const uint8_t A12 = 13;
static const uint8_t A13 = 14;
static const uint8_t A14 = 15;
static const uint8_t A15 = 16;
static const uint8_t A16 = 17;
static const uint8_t A17 = 18;
static const uint8_t A18 = 19;
static const uint8_t A19 = 20;

static const uint8_t T1 = 1;
static const uint8_t T2 = 2;
static const uint8_t T3 = 3;
static const uint8_t T4 = 4;
static const uint8_t T5 = 5;
static const uint8_t T6 = 6;
static const uint8_t T7 = 7;
static const uint8_t T8 = 8;
static const uint8_t T9 = 9;
static const uint8_t T10 = 10;
static const uint8_t T11 = 11;
static const uint8_t T12 = 12;
static const uint8_t T13 = 13;
static const uint8_t T14 = 14;

static const uint8_t DAC1 = 17;
static const uint8_t DAC2 = 18;

#endif /* Pins_Arduino_h */

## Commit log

2021-12-20 Added PostBoxSwitch struct instead button array
2021-12-20 Fixed first wakeup mqtt publish msg
    [main.cpp]
2021-12-20 Added WS2812b support for Switch_2
2021-12-20 Fixed switch counter and led strip feature
    [main.cpp]
2021-12-21 Updated iot-postbox sch and pcb to v0.2 correcting Switch references
    [iot-postbox.kicad_pcb, iot-postbox.sch]
2021-12-21 Exported pcb iot-postbox v0.3. Added ws2812b led strip to sch and pcb
    [iot-postbox-B_Cu.gbl, iot-postbox-B_Mask.gbs, iot-postbox-B_Paste.gbp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]
2022-03-24 Added Espressif kicad libs submodule and Kicad files for iot-postobox_v1
    [iot-postbox_v1.kicad_pcb, iot-postbox_v1.kicad_sch]
2022-06-09 Added iot-postbox v1.0 hardware designs
    [INTERFACE.kicad_sch, MCU.kicad_sch, POWER.kicad_sch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]
2022-06-09 Fixed PostBoxSwitch struct to make it compatible with esp32
    [main.cpp]
2022-06-10 Updated PCB desings readme
2022-06-14 Added iot-postbox_v1 sch to v1.1. Added minor documentation
    [INTERFACE.kicad_sch, MCU.kicad_sch, POWER.kicad_sch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]
2022-06-14 Ported fw to handle old and new iot-postbox boards. Added PostBoxSwitch class with SW interrupts
2022-06-15 Added esp32s2 deepsleep functions
2022-06-20 Added PostBox missing functions and instanced objec at main
    [PostBox.cpp, PostBox.h, main.cpp]
2022-06-24 Added test adc functions
2022-06-26 Cleaned ADC functions
2022-06-27 Enabled adc calibration and added debug
2022-06-28 Added adc calibration and average for vBat and debug thorugh webconfigserver dashboard
2022-07-01 Improved power and charging status recognition
2022-07-01 Changed led strip instance as fastled object insted adafruit neopixel and fixed power and charging states
    [MCU.kicad_sch, POWER.kicad_sch]
2022-07-02 INproved power status initialization and loop update
2022-07-02 Added charging circuit test findings
    [POWER.kicad_sch]
2022-07-02 Fixed wakeUp mask and gpio reason report
    [PostBox.cpp, PostBox.h, main.cpp]
2022-07-07 Updated iboom. Upgraded ADC array to 30 measures. Added IoT-PostBox_v1_4MB target
2022-07-07 Added some sch info
    [MCU.kicad_sch, POWER.kicad_sch]
2022-07-08 Added PowerStatus and ChargingStatus to publish payload
2022-07-08 Changed vBus min consider charge voltage to 4v
2022-07-10 Removed old adc sense variables
2022-07-12 Added PowerManagement class to handle power status, ADCSense and vBatStat inputs
2022-07-12 Added PowerManagement lib and removed old classes
2022-07-15 Fixed IoT-PostBox_v1 partition table
    [iotpostboxv1_16MB.csv]
2025-07-31 Add hardware doc files for ttl_to_usb_adapter board
    [ttl_to_usb_adapter.step]
2025-07-31 Move iot-postbox v1.0 bom and doc files to the correct location
    [iot-postbox_v1.csv, iot-postbox_v1.ods]
2025-07-31 Created iot-postbox v1.2 migrating to kicad v9. Fixed missing 3d designs, replaced horizontal footprints for some connectors.
    [INTERFACE.kicad_sch, MCU.kicad_sch, POWER.kicad_sch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]
2025-07-31 Export iot-postbox v1.2 hardware bom, gerber and doc files
    [iot-postbox_v1.csv]
2025-07-31 Fix pcb_desing readme.md with correct images for latest v1.2 version
2025-08-01 Remove obsolete panelized iot_postbox_v0.0 files from PCB designs
    [combined.drl, combined.gbl, combined.gbo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]
2025-08-01 Update readme for IoT-PostBox PCB designs, including detailed descriptions of hardware functionality, features, and version comparisons.
2025-08-01 Fix README.md for clarity and accuracy in hardware evolution and link to PCB designs
2025-08-03 Renamed schematic PDF for IoT-PostBox v1.2
2025-09-26 Fix wake-up bitmask definition in PostBox.h for correct GPIO usage with ESP-IDF v5
    [PostBox.h]
2025-09-26 Replace PubSubClient with MQTTClient v1.1.0. Bump WebConfigServer, PowerManagement, FastLED and MCCI LoRaWAN LMIC library to latest tested versions
    [PostBox.cpp, PostBox.h, main.cpp]
2025-09-26 Add IoT-PostBox v1 board variant files and upgrade pio env configuration
    [partitions.csv]
2025-09-26 Add IoT-PostBox 4MB version board variant files and update platformio target configuration
    [iotpostboxv1_4MB.csv, partitions.csv]
